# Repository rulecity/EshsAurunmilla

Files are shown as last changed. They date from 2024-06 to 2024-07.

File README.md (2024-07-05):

# Esh's Aurunmilla
(Mostly) 1:1 clone of the arcade game PCB for the Funai game, Esh's Aurunmilla

# Introduction
Esh's Aurunmilla was laserdisc game conversion for the 1983 Funai game Interstellar.  It is notoriously campy/cheesy with pretty bad voice acting.  In short, the game is so bad that it's good.

I became fascinated with this game some years ago and desired to own one.  Unfortunately, the PCB and laserdisc are both exceedingly rare.  So instead of finding originals of these items, I created reproductions.  I created a mostly 1:1 clone of the game PCB which is what this repository consists of.  After selling 20 of these clones to collectors and exhausting commercial demand, I decided to open source the whole thing for preservation.  What you have in this repository are the results of my efforts.

# PCBs
I created the PCB with Kicad v5.  I have tested these files on Kicad v6 and they seem to work fine.
I made two smaller PCBs to replace the original PROMs used on these games, which are very obsolete.  The small PCBs use CPLDs to mimic the behavior of the PROMs.  Unfortunately, these CPLDs have themselves become obsolete (I chose them because they were 5V tolerant on the inputs).  But someone who knows what they are doing should be able to update these with a new CPLD/FPGA if they want to badly enough.

I said before that the PCB is a mostly 1:1 clone.  I did change the laserdisc I/O port because the one on the original PCB was hopelessly non-standard.  I also removed some diagnostic stuff that was near the CPU on the original PCB as I saw no benefit to retaining it.  Otherwise, this clone should be nearly identical to the original, trace for trace.

# VHDL
I've included the simple VHDL source code programs I wrote for the two CPLDs.  I built with Xilinx ISE 14.7 which, last I checked, can be obtained for free as a linux VM that runs fine under Windows in VirtualBox.

# Bill of Materials
These are the actual spreadsheets I used when ordering parts for these PCBs.

# Test ROM
A test ROM I wrote from scratch to test PCBs before I shipped them off to customers.  Should be pretty comprehensive.

# More info
See http://www.rulecity.com/esh/

# Support
If you need help building the VHDL code, programming the CPLDs, or having PCBs made from the KiCad files, I offer commercial support: https://www.daphne-emu.com:9443/mediawiki/index.php/CommercialSupport

--Matt Ownby

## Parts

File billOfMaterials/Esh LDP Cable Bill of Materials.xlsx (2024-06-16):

Quantity | Reference | Manufacturer | Manufacturer Part Number | Distributor | Dist. Part Number | Note
1 |  |  |  |  | A1559-ND | LD-V1000 connector
1 |  |  |  |  | AE24G-300-ND | ribbon cable (300 feet)
1 |  |  |  |  | LKR26H-ND | female connector
 |  |  |  |  |  | 3.5 feet of ribbon per cable

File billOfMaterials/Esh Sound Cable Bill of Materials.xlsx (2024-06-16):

Quantity | Reference | Manufacturer | Manufacturer Part Number | Distributor | Dist. Part Number | Note
1 |  | JST | H4P-SHF-AA | Digikey | 455-4191-ND | 4-pin to sound PCB
1 |  | JST | H6P-SHF-AA | Digikey | 455-4193-ND | 6-pin to esh PCB
6 |  | JST | SHF-001T-0.8BS | Digikey | 455-1121-2-ND | JST pins (substitute: BHF-001T-0.8BS )
 |  |  |  |  |  | 2 feet of wires per cable
 |  |  |  |  |  | Pin 1 of the 6-pin connector is the audio signal and (I think) connects to pin 1 of the 4-pin connector.
 |  |  |  |  |  | Pins 2 and 4 are ground.
 |  |  |  |  |  | Pin 3 is the other audio channel used by Interstellar and is not used by Esh's so I leave it unconnected.

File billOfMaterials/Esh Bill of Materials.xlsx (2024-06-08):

Quantity | Reference | Manufacturer | Manufacturer Part Number | Distributor | Dist. Part Number | Note | Pins
1 |  |  |  | DigiKey | AE10008-ND | 40-pin socket
1 | L8 |  |  | jameco.com |  | Z80 CPU | 40
2 |  |  |  | DigiKey | AE10004-ND | 28-pin socket
2 | H8 F8 |  |  | jameco.com |  | 2764 | 28
5 |  |  |  | DigiKey | AE10001-ND | 24-pin socket
2 | J1 socket alternative |  |  | DigiKey | S7043-ND | To connect to PROM replacement PCB
1 | F3 |  |  | jameco.com |  | RAM 6116 150ms | 24
1 | B8 |  |  | jameco.com |  | RAM 6116 200ms | 24
3 | M3 L3 K3 |  |  | jameco.com |  | 2732 | 24
8 |  |  |  | DigiKey | AE9998-ND | 20-pin socket
3 | C1,C3,C4 |  |  | DigiKey | 296-1657-5-ND | 74LS273 | 20
2 | D4,F4 |  |  | DigiKey | 296-1655-5-ND | 74LS245 | 20
2 | F1 E1 |  |  | DigiKey | 296-1660-5-ND | 74LS373 | 20
1 | F7 |  |  | DigiKey | 296-1653-5-ND | 74LS244 | 20
0 | J1 |  | MB7124 |  |  | Use CPLD instead. PROM is too rare. | 20
28 |  |  |  | DigiKey | AE9992-ND | 16-pin socket
4 | C5,C6 socket alternative |  |  | DigiKey | S7041-ND | To connect to PROM replacement PCB
1 | B7 |  |  | DigiKey | 296-3702-5-ND | 74LS368 | 16
3 | A2,B2,C2 |  |  | DigiKey | 296-33981-5-ND | 74LS253 | 16
0 | C5,C6 |  | MB7052 | DigiKey |  | Use CPLD instead. PROMs overheat. | 16
1 | D2 |  |  | DigiKey | 497-2344-5-ND | ULN2003 | 16
6 | B6,B5,B4,B3,D7,C7 |  |  | DigiKey | 296-1646-5-ND | 74LS161 | 16
1 | D3 |  |  | DigiKey | 296-14889-5-ND | 74LS259 | 16
3 | D5 H5 J4 |  |  | DigiKey | 296-1640-5-ND | 74LS139 | 16
3 | E7 E6 E5 |  |  | DigiKey | 296-1645-5-ND | 74LS157 | 16
1 | H2 |  |  | DigiKey | 296-3654-5-ND | 74LS153 | 16
1 | H4 |  |  | DigiKey | 296-3664-5-ND | 74LS174 | 16
1 | H7 |  |  | DigiKey | 296-3701-5-ND | 74LS367 | 16
1 | J7 |  |  | DigiKey | 296-3655-5-ND | 74LS156 | 16
3 | K7 F6 F5 |  |  | DigiKey | 296-1639-5-ND | 74LS138 | 16
3 | M1 L1 K1 |  |  | DigiKey | 296-3662-5-ND | 74LS166 | 16
16 |  |  |  | DigiKey | AE9989-ND | 14-pin socket
2 | A2,A5 |  |  | DigiKey | 296-1633-5-ND | 74LS08 | 14
1 | A4 |  |  | DigiKey | 296-1669-5-ND | 74LS86 | 14
1 | A6 |  |  | DigiKey | 296-3693-5-ND | 74LS30 | 14
1 | D6 |  |  | DigiKey | 296-33952-5-ND | 74LS107 | 14
2 | F2 M5 |  |  | DigiKey | 296-1627-5-ND | 74LS02 | 14
2 | J5 K4 |  |  | DigiKey | 296-1658-5-ND | 74LS32 | 14
1 | J6 |  |  | DigiKey | 296-1626-ND | 74LS00 | 14
1 | K5 |  |  | DigiKey | 296-1634-5-ND | 74LS10 | 14
5 | L7 M7 M6 K6 H6 |  |  | DigiKey | 296-1668-5-ND | 74LS74 | 14
1 | BAT1 |  |  |  |  | 3-51FT-P
1 | CP1 |  |  | DigiKey | 493-1743-ND | 470uF, 16V. 8mm Diameter, 5mm Pin
1 | CP2 |  |  | DigiKey | 493-15966-1-ND | 10uF, 16V. 5mm diameter, 2.5mm pin
1 | CP27 |  |  | DigiKey | 399-14048-ND | 350pF
1 | CP28 |  |  | DigiKey | 399-8916-ND | 20pF, to match crystal. Mike Treu said 33pF worked better for him.
1 | CN1 | JST | B6P-SHF-1AA(LF)(SN) | DigiKey | 455-4181-ND | Audio connector
1 | CN5 | Amphenol | 71918-126LF | DigiKey | 609-1756-ND | LD-V1000 Connector
69 | CP# |  |  | DigiKey | 399-9759-ND | 0.1uF
1 | DIODE1 |  |  | DigiKey | BZX85C6V2-TAPGICT-ND | BZX85C6V2
2 | DIODE2,DIODE3 |  |  | DigiKey | 1N4148FS-ND | 1N4148
1 | Q1 | Microchip | MCP120-450GI/TO | DigiKey | MCP120-450GI/TO-ND
1 | R1 |  |  | DigiKey | CF14JT1K20CT-ND | 1.2k
1 | R13 |  |  | DigiKey | S100HCT-ND | 100 Ohm, 1/2W
5 | R17 R27 R22 R16 R9 |  |  | DigiKey | CF14JT1K00CT-ND | 1k
1 | R18 |  |  | DigiKey | CF14JT100RCT-ND | 100
3 | R2 R26 R25 |  |  | DigiKey | CF14JT10K0CT-ND | 10k
2 | R21 R20 |  |  | DigiKey | CF14JT330RCT-ND | 330
5 | R23 R19 R7 R6 R3 |  |  | DigiKey | CF14JT220RCT-ND | 220
4 | R8 R5 R4 R24 |  |  | DigiKey | CF14JT470RCT-ND | 470
4 | RA10 RA1 RA2 RA3 |  |  | DigiKey | 4609X-101-102LF-ND | 1k array
6 | RA4 RA7 RA5 RA8 RA6 RA9 |  |  | DigiKey | 770-83-R220P-ND | 220, series
1 | X1 | Fox | FC4STCBMF18.432-BAG200 | DigiKey | 631-1109-ND

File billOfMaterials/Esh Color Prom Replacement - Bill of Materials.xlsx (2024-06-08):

Quantity | Reference | Manufacturer | Manufacturer Part Number | Distributor | Dist. Part Number | Note
1 | U4 | TI | LMS8117AMP-3.3/NOPB | Digikey | LMS8117AMP-3.3/NOPBTR-ND | 3.3V reg
1 | U3 | Xilinx |  | Digikey | 122-1465-ND | CPLD
1 | R1 | Panasonic | ERJ-8GEYJ331V | Digikey | P330ECT-ND | 330 Ohm
3 | CP6, CP7, CP8 | Wurth | 885012208009 | Digikey | 732-8086-1-ND | 0.1 uF
2 | CP4,CP5, CP9 | Vishay | TL3A106K010C2000 | Digikey | 718-TL3A106K010C2000CT-ND | 10 uF as recommended by voltage reg; alternate non-polarized CL31B106KOHNFNE
1 | D1 | Kingbright Company LLC | APT3216SGC | Digi-Key | 754-1141-1-ND
2 | J1 pins alternate |  | M20-9731045 | Digikey | 952-1841-ND | Pairs with S7043-ND
1 | J2 |  |  | Digikey | 2057-PH2-14-UA-ND | JTAG Interface

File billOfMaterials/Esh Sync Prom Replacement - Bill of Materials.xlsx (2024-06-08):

Quantity | Reference | Manufacturer | Manufacturer Part Number | Distributor | Dist. Part Number | Note
1 | U4 |  |  | Digikey | 497-1241-1-ND | 3.3V reg
1 | U3 | Xilinx | XC9536XL-5VQG44C | Digikey | 122-1465-ND | CPLD
1 | R1 |  |  | Digikey | P330GCT-ND | 330 Ohm
4 | CP4, CP6, CP7, CP8 |  |  | Digikey | 720-1688-1-ND | 0.1 uF
2 | CP5, CP9 |  |  | Digikey | 490-12736-2-ND | 10 uF
1 | D1 | Kingbright Company LLC | APT3216SGC | Digi-Key | 754-1141-1-ND
4 | C5,C6 pins alternate |  |  | Digikey | 952-1999-ND | Pairs with S7041-ND
1 | J1 |  |  | Digikey | 2057-PH2-14-UA-ND | JTAG Interface

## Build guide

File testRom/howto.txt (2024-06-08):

Esh's Aurunmilla Test ROM Program v5
Written by Matt Ownby, Nov 2023
------------------------------------

I wrote this test ROM program in order to rapidly test reproduction Esh PCBs.

It tests almost everything on the PCB and presents the results on the screen.

The ROM test tests for the presence of a specific F8 Esh ROM that has the
 following MD5:

98ae491f23972416ef4edf5ae323a6a7  f8_is2.bin

TO ASSEMBLE:
------------

From ubuntu/bash:

$ sudo apt install z80asm m4
$ m4 esh_test.m4 > esh_test.asm
$ z80asm esh_test.asm -o h8_is1.bin

HOW TO USE:
-----------

- If you see "BAD RAM", then the CPU cannot read/write reliably to the RAM at B8.

- If the F8 ROM test fails, then CPU cannot confirm that the ROM shown above is installed at F8.

- If the strobe test fails, CPU is not getting status strobes from the LD-V1000 laserdisc player.  Check F2 and L7.

- If the LDP I/O test fails, CPU is not getting expected results from the LD-V1000 laserdisc player when trying to search to a specific frame. Check E1, F1 and F2.

- If the color palette and graphics shown at the top of the screen are unexpected, the color PROM and/or graphics EPROMs may have problems.

- If the background shown (either blue, black, or disc) is different from what the text is showing should be displyed, there may be a problem with the color PROM or H1.

- If you do not see "1X 2X 4X" text actively blinking, there may be a problem with H1.

- If you do not hear a beep when holding down the action button, there may be a problem with H1 or E2 or you do not have audio cable connected.

- If not all inputs are showing up when you press them on the control panel, there may be a problem with A2, B2, or C2.

- If the lamps indicated do not light up, there may be a problem with D2 or D3.

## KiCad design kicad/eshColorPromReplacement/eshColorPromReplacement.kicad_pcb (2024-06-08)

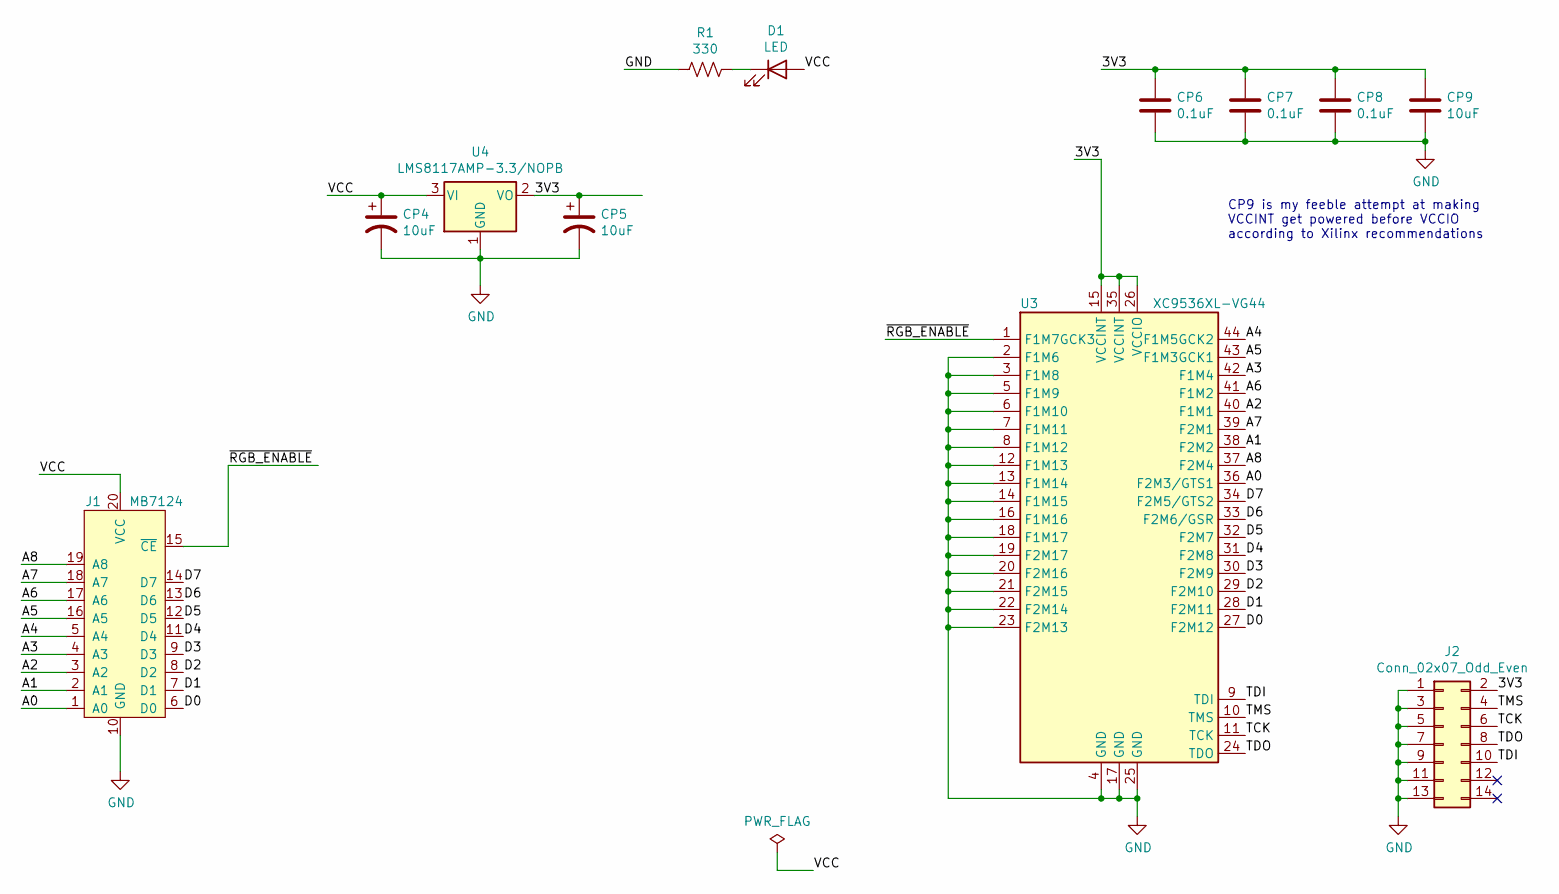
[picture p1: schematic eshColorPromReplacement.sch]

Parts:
CP4, CP5, CP9: 10uF; C_1206_3216Metric
CP6, CP7, CP8: 0.1uF; C_1206_3216Metric
D1: LED; LED_1206_3216Metric
J1: MB7124; DIP-20_W7.62mm_Socket
J2: Conn_02x07_Odd_Even; PinHeader_2x07_P2.54mm_Vertical
R1: 330; R_1206_3216Metric
U3: XC9536XL-VG44; TQFP-44_10x10mm_P0.8mm
U4: LMS8117AMP-3.3/NOPB; SOT-223-3_TabPin2

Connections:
/3V3: CP5.1, CP6.1, CP7.1, CP8.1, CP9.1, J2.2, U3.15 (VCCINT), U3.26 (VCCIO), U3.35 (VCCINT), U4.2 (VO)
/A0: J1.1 (A0), U3.36 (F2M3/GTS1)
/A1: J1.2 (A1), U3.38 (F2M2)
/A2: J1.3 (A2), U3.40 (F1M1)
/A3: J1.4 (A3), U3.42 (F1M4)
/A4: J1.5 (A4), U3.44 (F1M5GCK2)
/A5: J1.16 (A5), U3.43 (F1M3GCK1)
/A6: J1.17 (A6), U3.41 (F1M2)
/A7: J1.18 (A7), U3.39 (F2M1)
/A8: J1.19 (A8), U3.37 (F2M4)
/D0: J1.6 (D0), U3.27 (F2M12)
/D1: J1.7 (D1), U3.28 (F2M11)
/D2: J1.8 (D2), U3.29 (F2M10)
/D3: J1.9 (D3), U3.30 (F2M9)
/D4: J1.11 (D4), U3.31 (F2M8)
/D5: J1.12 (D5), U3.32 (F2M7)
/D6: J1.13 (D6), U3.33 (F2M6/GSR)
/D7: J1.14 (D7), U3.34 (F2M5/GTS2)
/TCK: J2.6, U3.11 (TCK)
/TDI: J2.10, U3.9 (TDI)
/TDO: J2.8, U3.24 (TDO)
/TMS: J2.4, U3.10 (TMS)
/VCC: CP4.1, D1.2 (A), J1.20 (VCC), U4.3 (VI)
/~RGB_ENABLE: J1.15 (~CE), U3.1 (F1M7GCK3)
GND: CP4.2, CP5.2, CP6.2, CP7.2, CP8.2, CP9.2, J1.10 (GND), J2.1, J2.3, J2.5, J2.7, J2.9, J2.11, J2.13, R1.2, U3.2 (F1M6), U3.3 (F1M8), U3.4 (GND), U3.5 (F1M9), U3.6 (F1M10), U3.7 (F1M11), U3.8 (F1M12), U3.12 (F1M13), U3.13 (F1M14), U3.14 (F1M15), U3.16 (F1M16), U3.17 (GND), U3.18 (F1M17), U3.19 (F2M17), U3.20 (F2M16), U3.21 (F2M15), U3.22 (F2M14), U3.23 (F2M13), U3.25 (GND), U4.1 (GND)
unnamed: D1.1 (K), R1.1

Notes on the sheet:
CP9 is my feeble attempt at making VCCINT get powered before VCCIO according to Xilinx recommendations

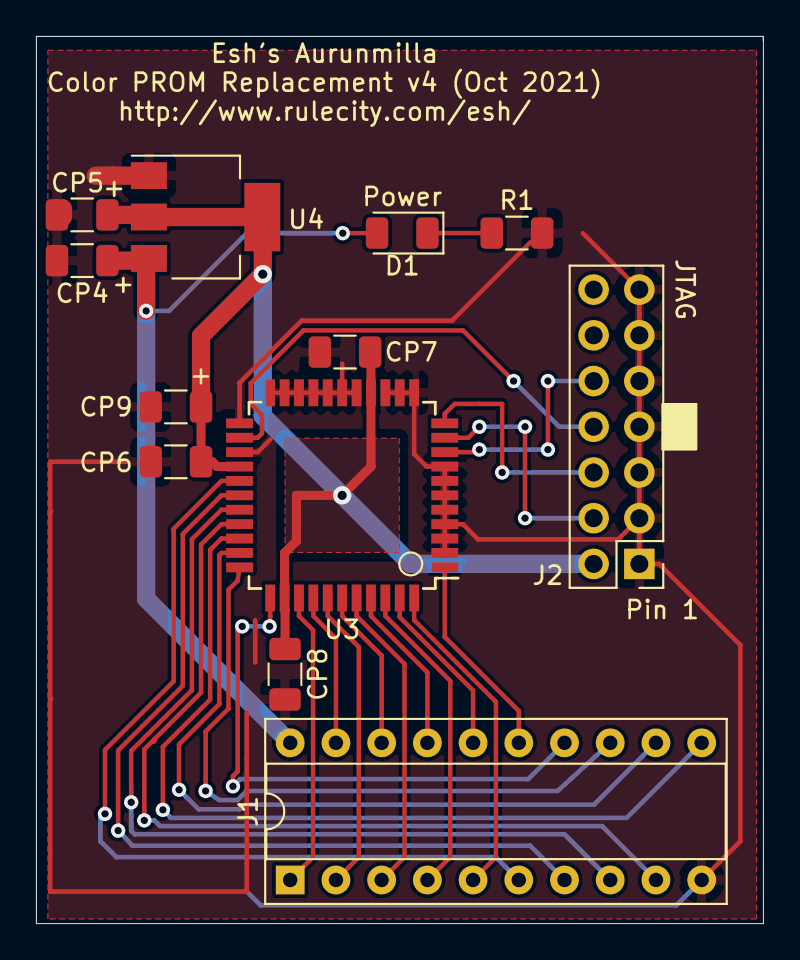
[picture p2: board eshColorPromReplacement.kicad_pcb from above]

Board: 2 copper layers, 40.4 x 49.3 mm, 12 parts (0 on the bottom side), 26 nets.

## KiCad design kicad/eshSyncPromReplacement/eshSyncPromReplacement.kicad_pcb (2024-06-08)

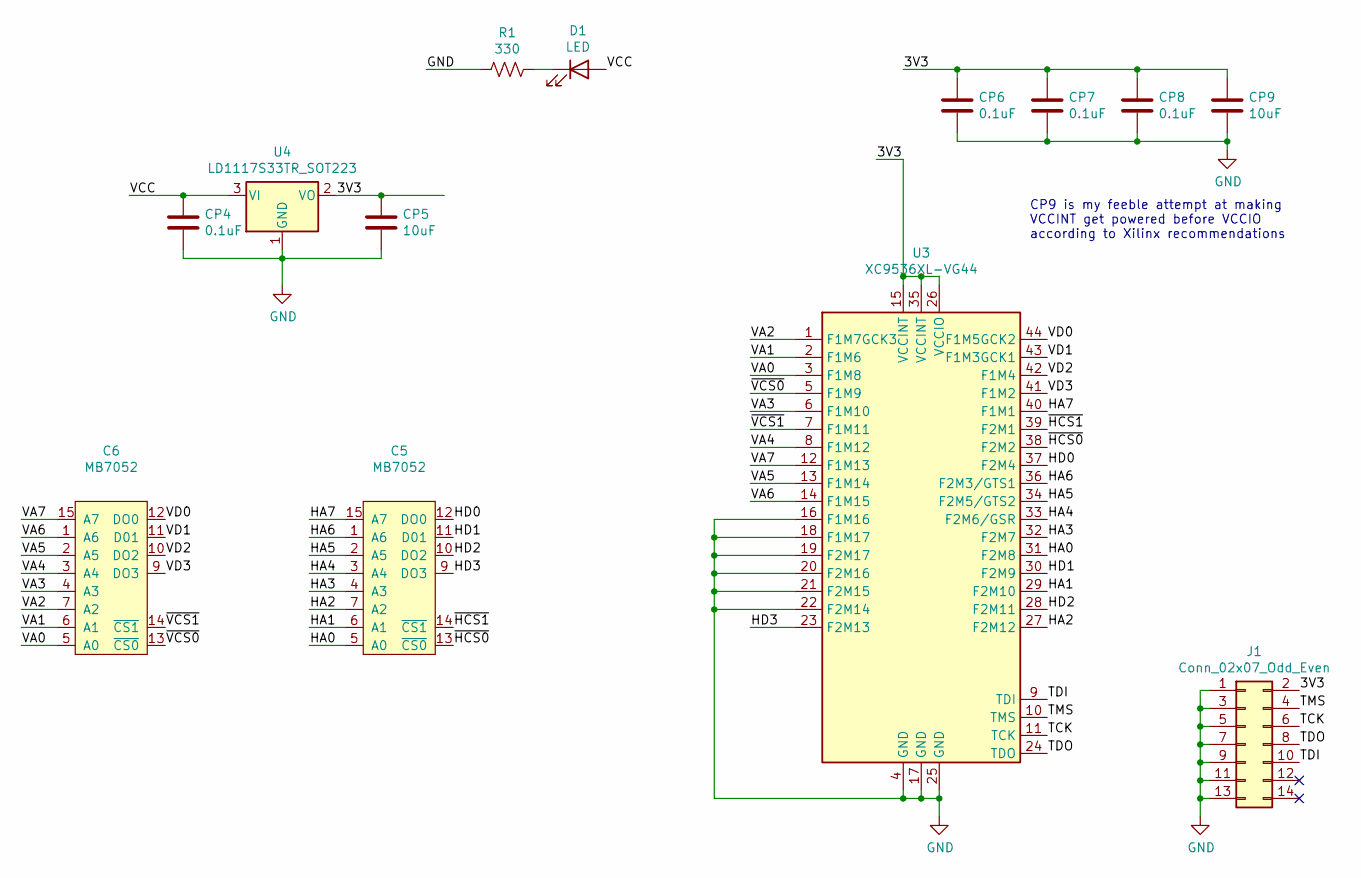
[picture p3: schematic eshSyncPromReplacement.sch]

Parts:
C5, C6: MB7052; DIP-16_W7.62mm_Socket
CP4, CP6, CP7, CP8: 0.1uF; C_0603_1608Metric
CP5, CP9: 10uF; C_0603_1608Metric
D1: LED; LED_1206_3216Metric
J1: Conn_02x07_Odd_Even; PinHeader_2x07_P2.54mm_Vertical
R1: 330; R_0603_1608Metric
U3: XC9536XL-VG44; TQFP-44_10x10mm_P0.8mm
U4: LD1117S33TR_SOT223; SOT-223-3_TabPin2

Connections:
/3V3: CP5.1, CP6.1, CP7.1, CP8.1, CP9.1, J1.2, U3.15 (VCCINT), U3.26 (VCCIO), U3.35 (VCCINT), U4.2 (VO)
/HA0: C5.5 (A0), U3.31 (F2M8)
/HA1: C5.6 (A1), U3.29 (F2M10)
/HA2: C5.7 (A2), U3.27 (F2M12)
/HA3: C5.4 (A3), U3.32 (F2M7)
/HA4: C5.3 (A4), U3.33 (F2M6/GSR)
/HA5: C5.2 (A5), U3.34 (F2M5/GTS2)
/HA6: C5.1 (A6), U3.36 (F2M3/GTS1)
/HA7: C5.15 (A7), U3.40 (F1M1)
/HD0: C5.12 (DO0), U3.37 (F2M4)
/HD1: C5.11 (D01), U3.30 (F2M9)
/HD2: C5.10 (DO2), U3.28 (F2M11)
/HD3: C5.9 (DO3), U3.23 (F2M13)
/TCK: J1.6, U3.11 (TCK)
/TDI: J1.10, U3.9 (TDI)
/TDO: J1.8, U3.24 (TDO)
/TMS: J1.4, U3.10 (TMS)
/VA0: C6.5 (A0), U3.3 (F1M8)
/VA1: C6.6 (A1), U3.2 (F1M6)
/VA2: C6.7 (A2), U3.1 (F1M7GCK3)
/VA3: C6.4 (A3), U3.6 (F1M10)
/VA4: C6.3 (A4), U3.8 (F1M12)
/VA5: C6.2 (A5), U3.13 (F1M14)
/VA6: C6.1 (A6), U3.14 (F1M15)
/VA7: C6.15 (A7), U3.12 (F1M13)
/VD0: C6.12 (DO0), U3.44 (F1M5GCK2)
/VD1: C6.11 (D01), U3.43 (F1M3GCK1)
/VD2: C6.10 (DO2), U3.42 (F1M4)
/VD3: C6.9 (DO3), U3.41 (F1M2)
/~HCS0: C5.13 (~CS0), U3.38 (F2M2)
/~HCS1: C5.14 (~CS1), U3.39 (F2M1)
/~VCS0: C6.13 (~CS0), U3.5 (F1M9)
/~VCS1: C6.14 (~CS1), U3.7 (F1M11)
GND: C5.8 (GND), C6.8 (GND), CP4.2, CP5.2, CP6.2, CP7.2, CP8.2, CP9.2, J1.1, J1.3, J1.5, J1.7, J1.9, J1.11, J1.13, R1.2, U3.4 (GND), U3.16 (F1M16), U3.17 (GND), U3.18 (F1M17), U3.19 (F2M17), U3.20 (F2M16), U3.21 (F2M15), U3.22 (F2M14), U3.25 (GND), U4.1 (GND)
unnamed: D1.1 (K), R1.1
VCC: C5.16 (VCC), C6.16 (VCC), CP4.1, D1.2 (A), U4.3 (VI)

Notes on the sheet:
CP9 is my feeble attempt at making VCCINT get powered before VCCIO according to Xilinx recommendations

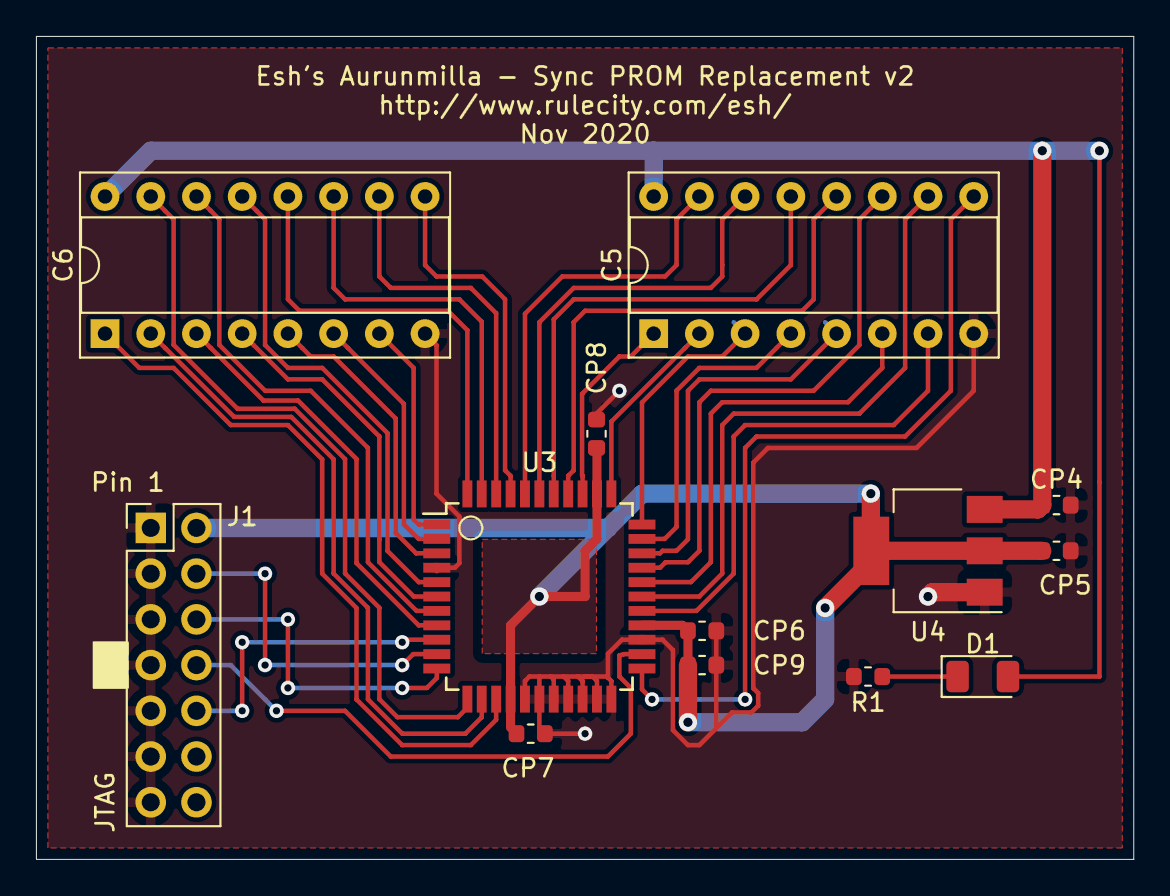
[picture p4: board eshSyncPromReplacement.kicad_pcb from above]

Board: 2 copper layers, 61.0 x 45.7 mm, 13 parts (0 on the bottom side), 36 nets.

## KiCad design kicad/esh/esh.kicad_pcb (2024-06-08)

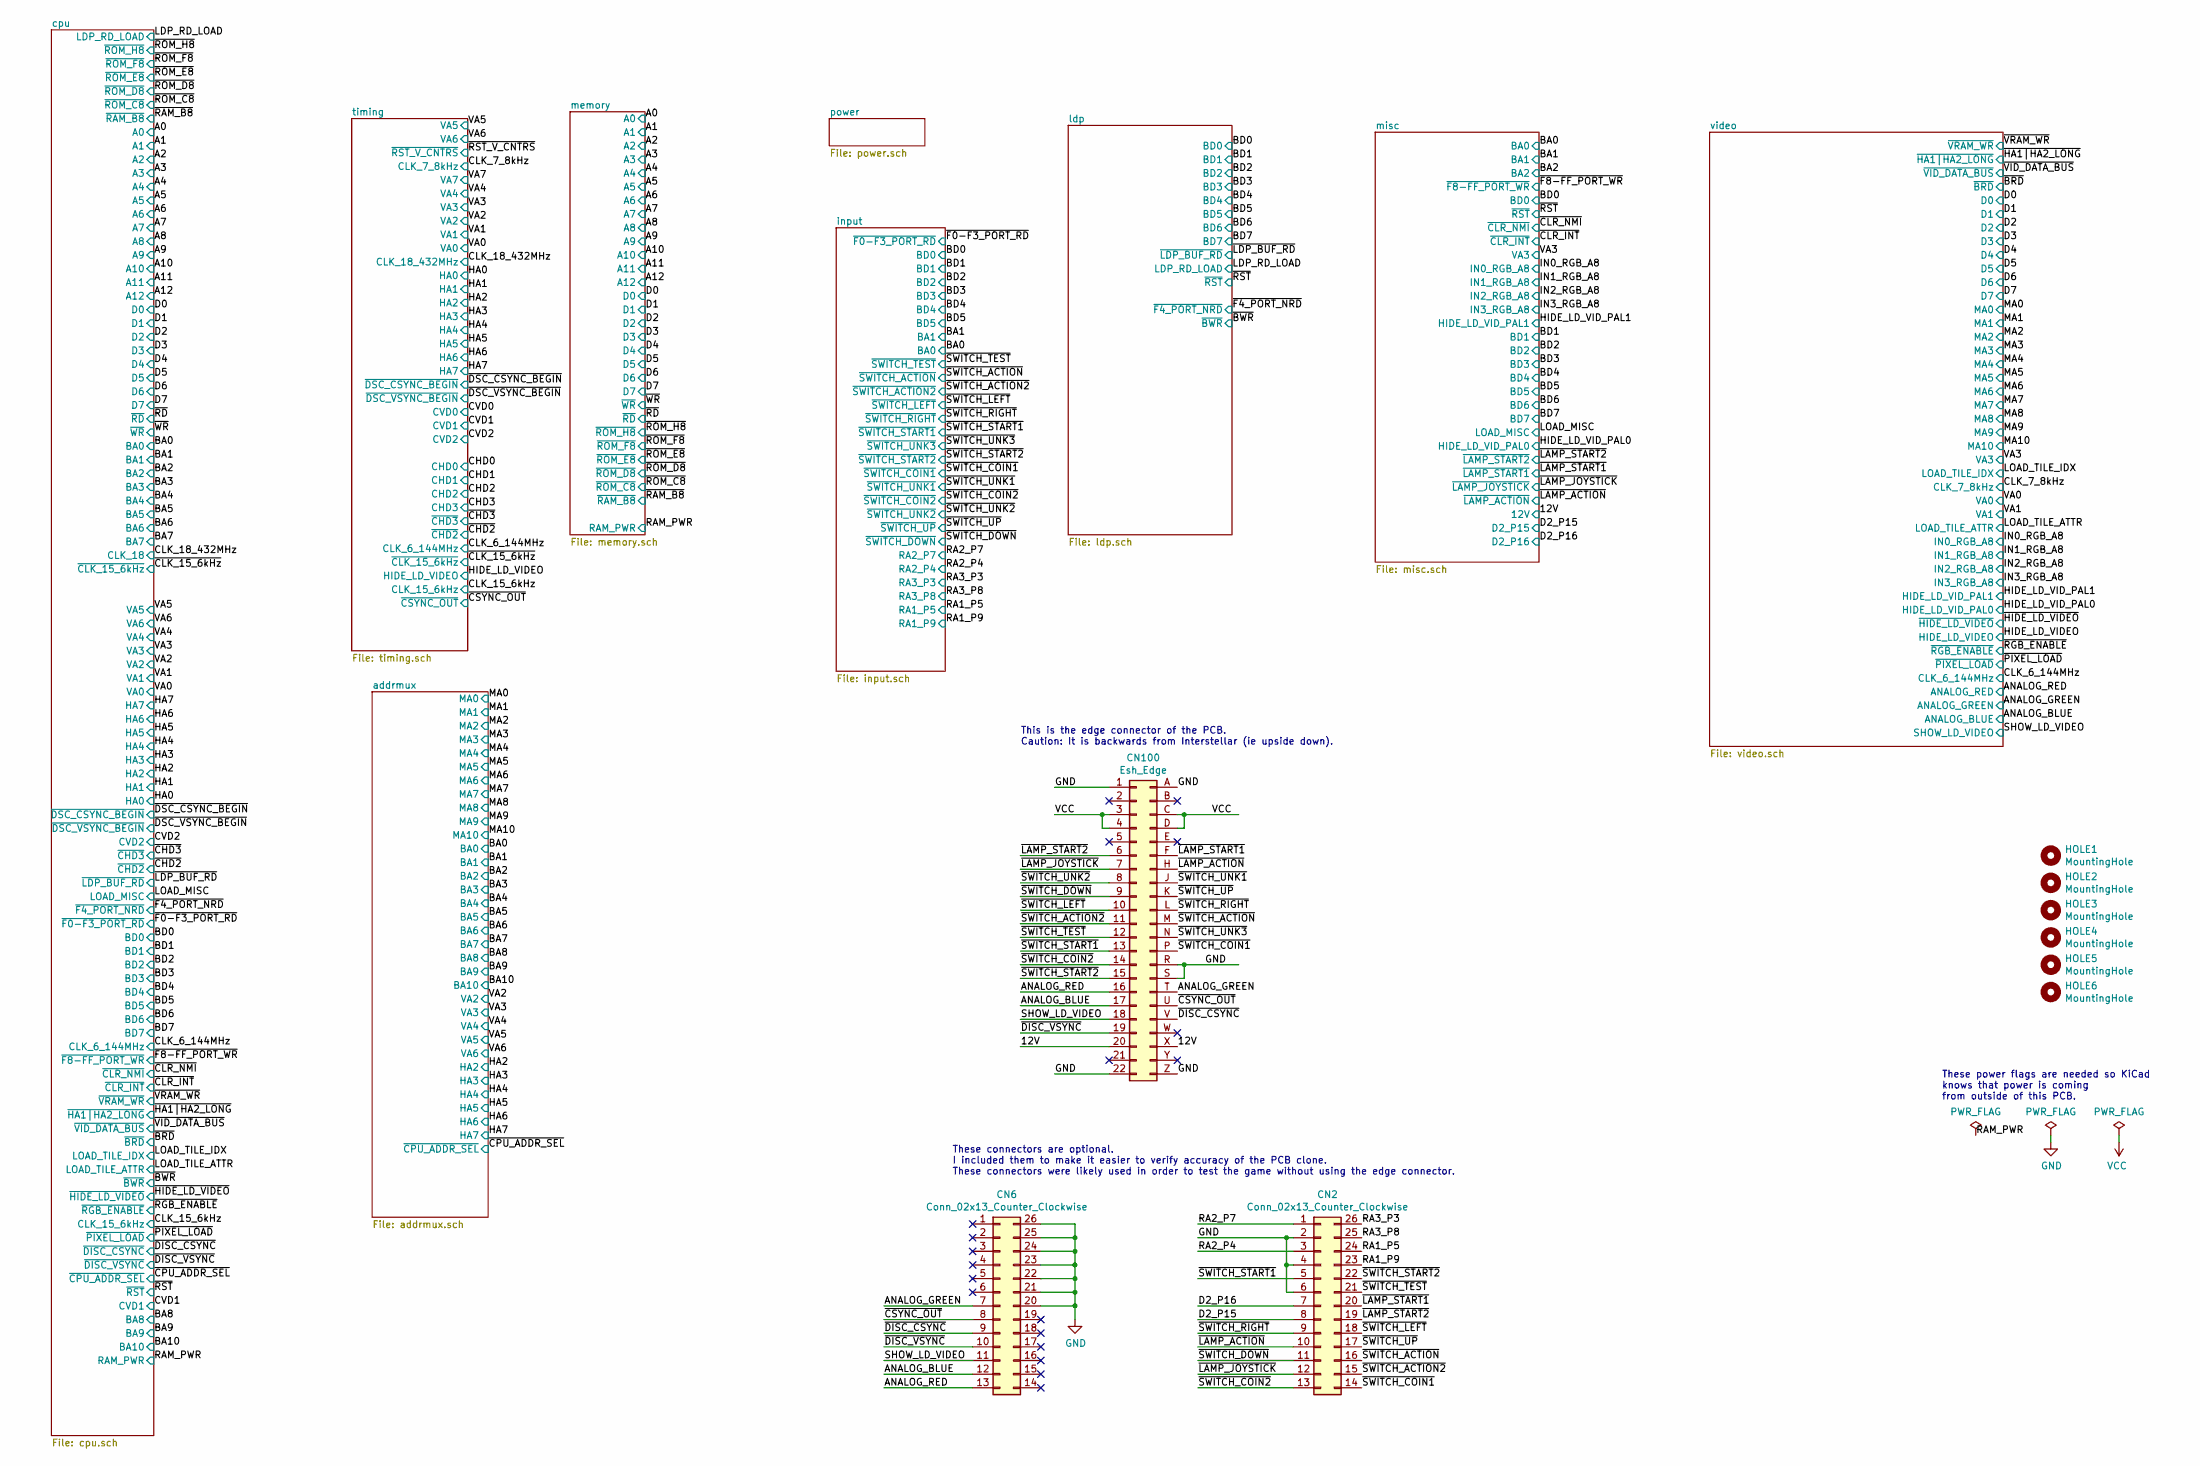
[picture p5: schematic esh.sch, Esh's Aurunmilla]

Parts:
CN2, CN6: Conn_02x13_Counter_Clockwise; 2x13Connector
CN100: Esh_Edge
HOLE1, HOLE2, HOLE3, HOLE4, HOLE5, HOLE6: MountingHole; MountingHole_4mm

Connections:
/12V: CN100.20, CN100.X; also elsewhere on the board
/ANALOG_BLUE: CN6.12, CN100.17; also elsewhere on the board
/ANALOG_GREEN: CN6.7, CN100.T; also elsewhere on the board
/ANALOG_RED: CN6.13, CN100.16; also elsewhere on the board
/D2_P15: CN2.8; also elsewhere on the board
/D2_P16: CN2.7; also elsewhere on the board
/RA1_P5: CN2.24; also elsewhere on the board
/RA1_P9: CN2.23; also elsewhere on the board
/RA2_P4: CN2.3; also elsewhere on the board
/RA2_P7: CN2.1; also elsewhere on the board
/RA3_P3: CN2.26; also elsewhere on the board
/RA3_P8: CN2.25; also elsewhere on the board
/SHOW_LD_VIDEO: CN6.11, CN100.18; also elsewhere on the board
/~CSYNC_OUT: CN6.8, CN100.U; also elsewhere on the board
/~DISC_CSYNC: CN6.9, CN100.V; also elsewhere on the board
/~DISC_VSYNC: CN6.10, CN100.19; also elsewhere on the board
/~LAMP_ACTION: CN2.10, CN100.H; also elsewhere on the board
/~LAMP_JOYSTICK: CN2.12, CN100.7; also elsewhere on the board
/~LAMP_START1: CN2.20, CN100.F; also elsewhere on the board
/~LAMP_START2: CN2.19, CN100.6; also elsewhere on the board
/~SWITCH_ACTION: CN2.16, CN100.M; also elsewhere on the board
/~SWITCH_ACTION2: CN2.15, CN100.11; also elsewhere on the board
/~SWITCH_COIN1: CN2.14, CN100.P; also elsewhere on the board
/~SWITCH_COIN2: CN2.13, CN100.14; also elsewhere on the board
/~SWITCH_DOWN: CN2.11, CN100.9; also elsewhere on the board
/~SWITCH_LEFT: CN2.18, CN100.10; also elsewhere on the board
/~SWITCH_RIGHT: CN2.9, CN100.L; also elsewhere on the board
/~SWITCH_START1: CN2.5, CN100.13; also elsewhere on the board
/~SWITCH_START2: CN2.22, CN100.15; also elsewhere on the board
/~SWITCH_TEST: CN2.21, CN100.12; also elsewhere on the board
/~SWITCH_UNK1: CN100.J; also elsewhere on the board
/~SWITCH_UNK2: CN100.8; also elsewhere on the board
/~SWITCH_UNK3: CN100.N; also elsewhere on the board
/~SWITCH_UP: CN2.17, CN100.K; also elsewhere on the board
GND: CN2.2, CN2.4, CN2.6, CN6.20, CN6.21, CN6.22, CN6.23, CN6.24, CN6.25, CN6.26, CN100.1, CN100.22, CN100.A, CN100.R, CN100.S, CN100.Z; also elsewhere on the board
VCC: CN100.3, CN100.4, CN100.C, CN100.D; also elsewhere on the board

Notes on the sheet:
These power flags are needed so KiCad knows that power is coming from outside of this PCB.
These connectors are optional. I included them to make it easier to verify accuracy of the PCB clone. These connectors were likely used in order to test the game without using the edge connector.
This is the edge connector of the PCB. Caution: It is backwards from Interstellar (ie upside down).

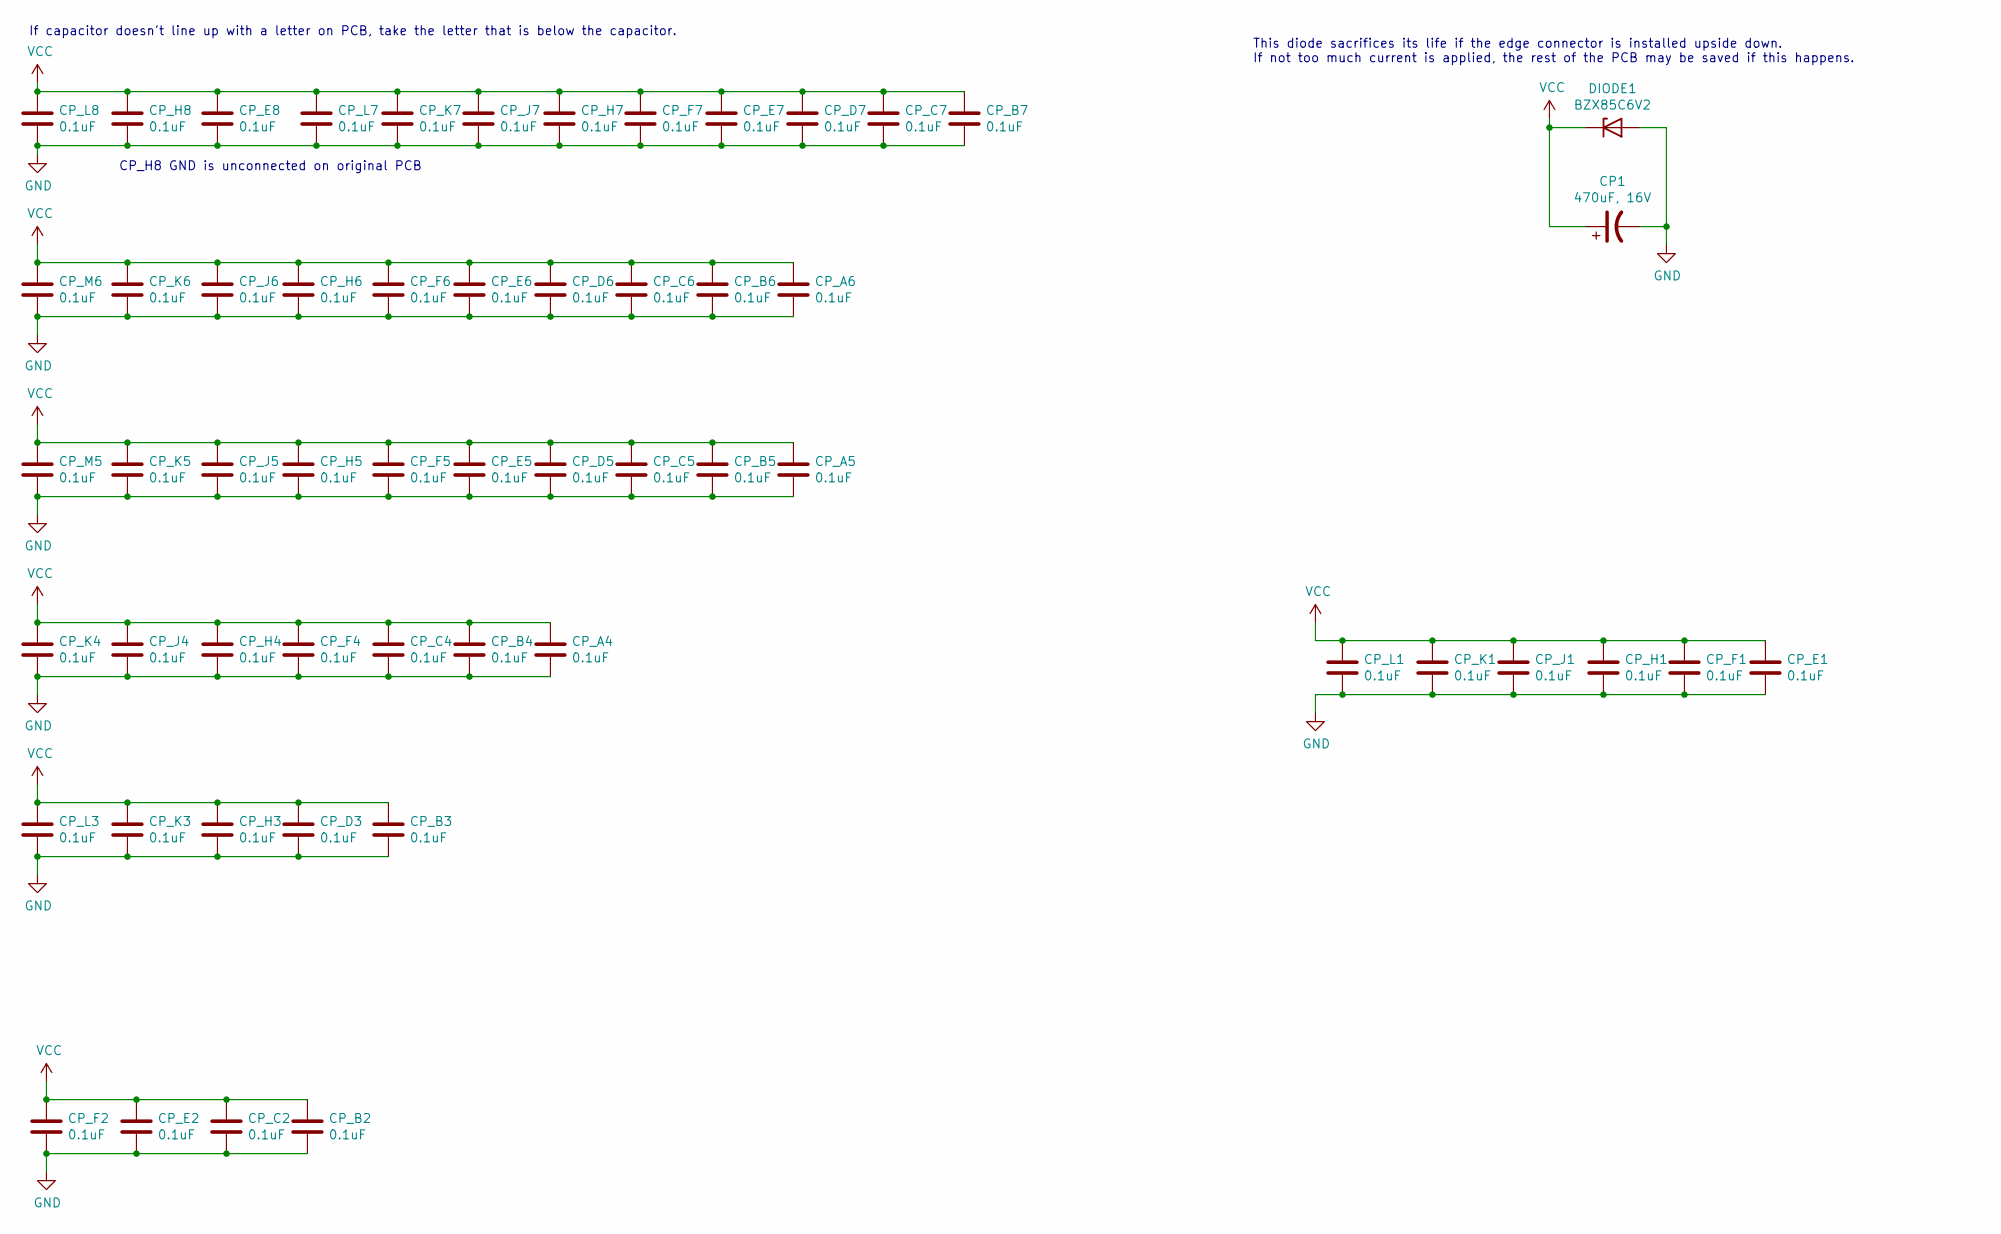
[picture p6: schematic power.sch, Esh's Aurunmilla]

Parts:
CP1: 470uF, 16V; CP_Radial_D8.0mm_P5.00mm
CP_A4, CP_A5, CP_A6: 0.1uF; R_Axial_DIN0204_L3.6mm_D1.6mm_P5.08mm_Horizontal
CP_B2, CP_B3, CP_B4, CP_B5, CP_B6, CP_B7: 0.1uF; R_Axial_DIN0204_L3.6mm_D1.6mm_P5.08mm_Horizontal
CP_C2, CP_C4, CP_C5, CP_C6, CP_C7: 0.1uF; R_Axial_DIN0204_L3.6mm_D1.6mm_P5.08mm_Horizontal
CP_D3, CP_D5, CP_D6, CP_D7: 0.1uF; R_Axial_DIN0204_L3.6mm_D1.6mm_P5.08mm_Horizontal
CP_E1, CP_E2, CP_E5, CP_E6, CP_E7, CP_E8: 0.1uF; R_Axial_DIN0204_L3.6mm_D1.6mm_P5.08mm_Horizontal
CP_F1, CP_F2, CP_F4, CP_F5, CP_F6, CP_F7: 0.1uF; R_Axial_DIN0204_L3.6mm_D1.6mm_P5.08mm_Horizontal
CP_H1, CP_H3, CP_H4, CP_H5, CP_H6, CP_H7, CP_H8: 0.1uF; R_Axial_DIN0204_L3.6mm_D1.6mm_P5.08mm_Horizontal
CP_J1, CP_J4, CP_J5, CP_J6, CP_J7: 0.1uF; R_Axial_DIN0204_L3.6mm_D1.6mm_P5.08mm_Horizontal
CP_K1, CP_K3, CP_K4, CP_K5, CP_K6, CP_K7: 0.1uF; R_Axial_DIN0204_L3.6mm_D1.6mm_P5.08mm_Horizontal
CP_L1, CP_L3, CP_L7, CP_L8: 0.1uF; R_Axial_DIN0204_L3.6mm_D1.6mm_P5.08mm_Horizontal
CP_M5, CP_M6: 0.1uF; R_Axial_DIN0204_L3.6mm_D1.6mm_P5.08mm_Horizontal
DIODE1: BZX85C6V2; D_T-1_P10.16mm_Horizontal

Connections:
GND: CP1.2, CP_A4.2, CP_A5.2, CP_A6.2, CP_B2.2, CP_B3.2, CP_B4.2, CP_B5.2, CP_B6.2, CP_B7.2, CP_C2.2, CP_C4.2, CP_C5.2, CP_C6.2, CP_C7.2, CP_D3.2, CP_D5.2, CP_D6.2, CP_D7.2, CP_E1.2, CP_E2.2, CP_E5.2, CP_E6.2, CP_E7.2, CP_E8.2, CP_F1.2, CP_F2.2, CP_F4.2, CP_F5.2, CP_F6.2, CP_F7.2, CP_H1.2, CP_H3.2, CP_H4.2, CP_H5.2, CP_H6.2, CP_H7.2, CP_H8.2, CP_J1.2, CP_J4.2, CP_J5.2, CP_J6.2, CP_J7.2, CP_K1.2, CP_K3.2, CP_K4.2, CP_K5.2, CP_K6.2, CP_K7.2, CP_L1.2, CP_L3.2, CP_L7.2, CP_L8.2, CP_M5.2, CP_M6.2, DIODE1.2 (A); also elsewhere on the board
VCC: CP1.1, CP_A4.1, CP_A5.1, CP_A6.1, CP_B2.1, CP_B3.1, CP_B4.1, CP_B5.1, CP_B6.1, CP_B7.1, CP_C2.1, CP_C4.1, CP_C5.1, CP_C6.1, CP_C7.1, CP_D3.1, CP_D5.1, CP_D6.1, CP_D7.1, CP_E1.1, CP_E2.1, CP_E5.1, CP_E6.1, CP_E7.1, CP_E8.1, CP_F1.1, CP_F2.1, CP_F4.1, CP_F5.1, CP_F6.1, CP_F7.1, CP_H1.1, CP_H3.1, CP_H4.1, CP_H5.1, CP_H6.1, CP_H7.1, CP_H8.1, CP_J1.1, CP_J4.1, CP_J5.1, CP_J6.1, CP_J7.1, CP_K1.1, CP_K3.1, CP_K4.1, CP_K5.1, CP_K6.1, CP_K7.1, CP_L1.1, CP_L3.1, CP_L7.1, CP_L8.1, CP_M5.1, CP_M6.1, DIODE1.1 (K); also elsewhere on the board

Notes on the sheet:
If capacitor doesn't line up with a letter on PCB, take the letter that is below the capacitor.
CP_H8 GND is unconnected on original PCB
This diode sacrifices its life if the edge connector is installed upside down. If not too much current is applied, the rest of the PCB may be saved if this happens.

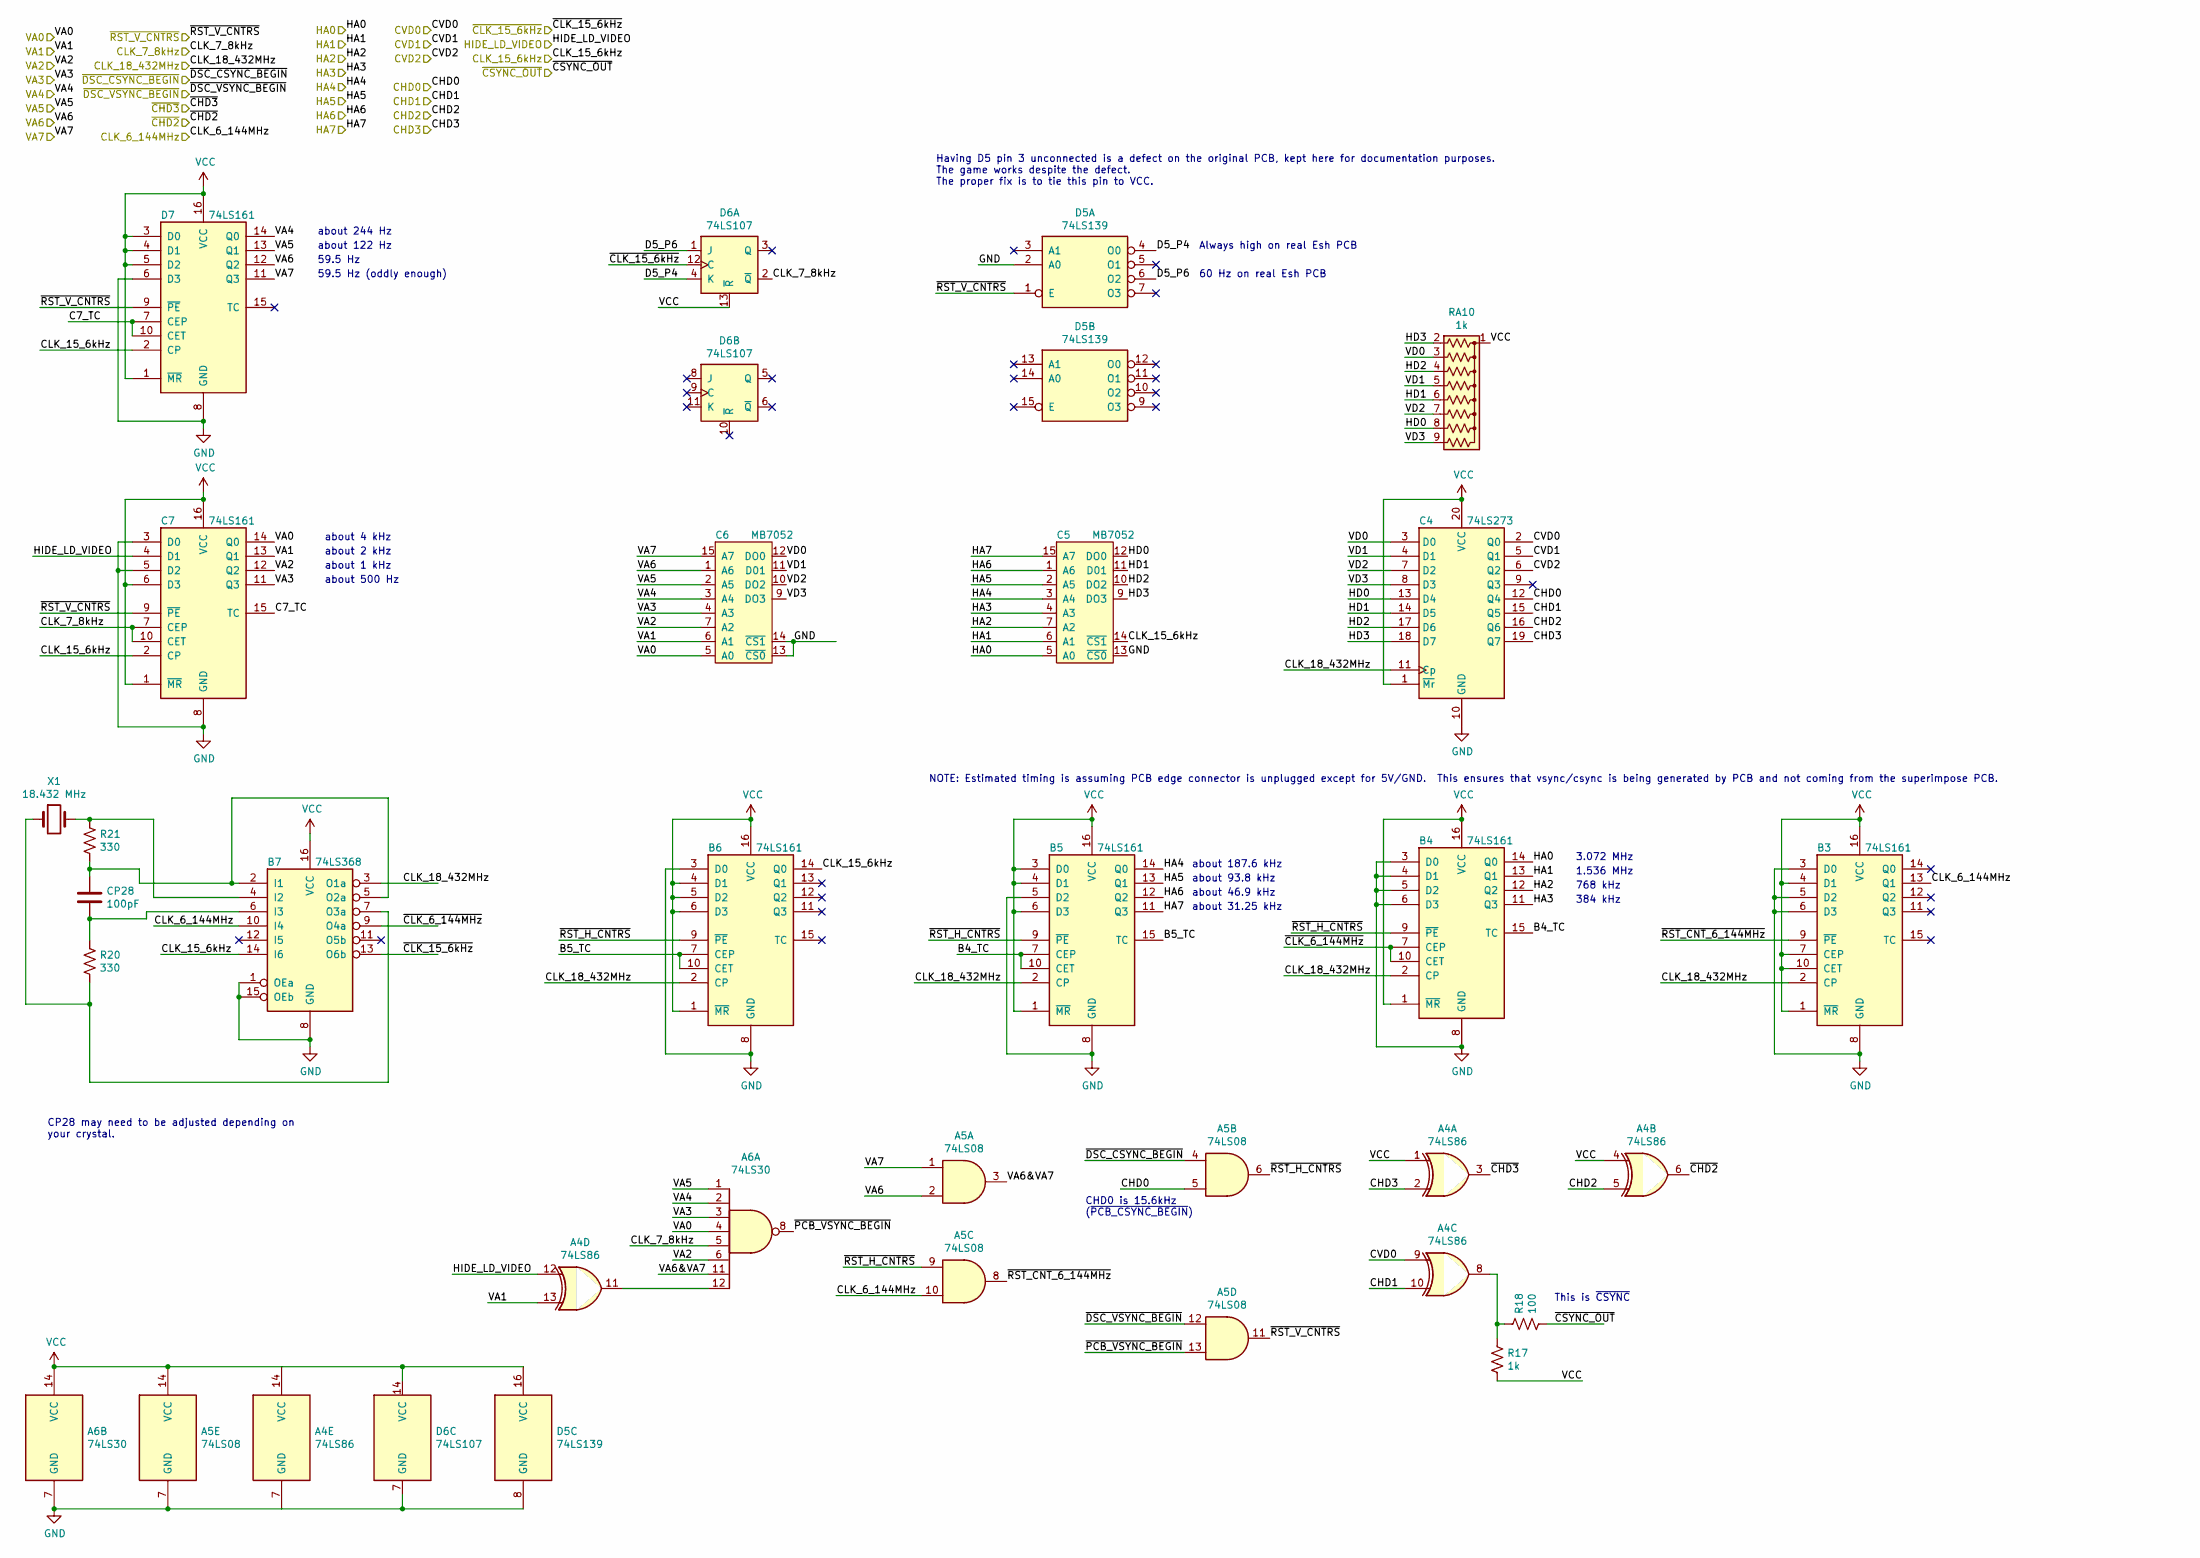
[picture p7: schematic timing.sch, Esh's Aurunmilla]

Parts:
A4: 74LS86; DIP-14_W7.62mm_Socket
A5: 74LS08; DIP-14_W7.62mm_Socket
A6: 74LS30; DIP-14_W7.62mm_Socket
B3, B4, B5, B6: 74LS161; DIP-16_W7.62mm_Socket
B7: 74LS368; DIP-16_W7.62mm_Socket
C4: 74LS273; DIP-20_W7.62mm_Socket
C5, C6: MB7052; DIP-16_W7.62mm_Socket
C7: 74LS161; DIP-16_W7.62mm_Socket
CP28: 100pF; R_Axial_DIN0204_L3.6mm_D1.6mm_P5.08mm_Horizontal
D5: 74LS139; DIP-16_W7.62mm_Socket
D6: 74LS107; DIP-14_W7.62mm_Socket
D7: 74LS161; DIP-16_W7.62mm_Socket
R17: 1k; R_Axial_DIN0207_L6.3mm_D2.5mm_P10.16mm_Horizontal
R18: 100; R_Axial_DIN0207_L6.3mm_D2.5mm_P10.16mm_Horizontal
R20, R21: 330; R_Axial_DIN0207_L6.3mm_D2.5mm_P10.16mm_Horizontal
RA10: 1k; R_Array_SIP9
X1: 18.432 MHz; Crystal_HC49-U_Vertical

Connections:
/CHD0: A5.5, C4.12 (Q4)
/CHD1: A4.10, C4.15 (Q5)
/CHD2: A4.5, C4.16 (Q6)
/CHD3: A4.2, C4.19 (Q7)
/CLK_6_144MHz: A5.10, B3.13 (Q1), B7.10 (I4); also elsewhere on the board
/CLK_7_8kHz: A6.5, C7.7 (CEP), C7.10 (CET), D6.2 (~Q); also elsewhere on the board
/CLK_15_6kHz: B6.14 (Q0), B7.14 (I6), C5.14 (~CS1), C7.2 (CP), D7.2 (CP); also elsewhere on the board
/CLK_18_432MHz: B3.2 (CP), B4.2 (CP), B5.2 (CP), B6.2 (CP), B7.3 (O1a), C4.11 (Cp); also elsewhere on the board
/CVD0: A4.9, C4.2 (Q0)
/CVD1: C4.5 (Q1); also elsewhere on the board
/CVD2: C4.6 (Q2); also elsewhere on the board
/HA0: B4.14 (Q0), C5.5 (A0); also elsewhere on the board
/HA1: B4.13 (Q1), C5.6 (A1); also elsewhere on the board
/HA2: B4.12 (Q2), C5.7 (A2); also elsewhere on the board
/HA3: B4.11 (Q3), C5.4 (A3); also elsewhere on the board
/HA4: B5.14 (Q0), C5.3 (A4); also elsewhere on the board
/HA5: B5.13 (Q1), C5.2 (A5); also elsewhere on the board
/HA6: B5.12 (Q2), C5.1 (A6); also elsewhere on the board
/HA7: B5.11 (Q3), C5.15 (A7); also elsewhere on the board
/HIDE_LD_VIDEO: A4.12, C7.4 (D1); also elsewhere on the board
/VA0: A6.4, C6.5 (A0), C7.14 (Q0); also elsewhere on the board
/VA1: A4.13, C6.6 (A1), C7.13 (Q1); also elsewhere on the board
/VA2: A6.6, C6.7 (A2), C7.12 (Q2); also elsewhere on the board
/VA3: A6.3, C6.4 (A3), C7.11 (Q3); also elsewhere on the board
/VA4: A6.2, C6.3 (A4), D7.14 (Q0); also elsewhere on the board
/VA5: A6.1, C6.2 (A5), D7.13 (Q1); also elsewhere on the board
/VA6: A5.2, C6.1 (A6), D7.12 (Q2); also elsewhere on the board
/VA7: A5.1, C6.15 (A7), D7.11 (Q3)
/timing/B4_TC: B4.15 (TC), B5.7 (CEP), B5.10 (CET)
/timing/B5_TC: B5.15 (TC), B6.7 (CEP), B6.10 (CET)
/timing/C7_TC: C7.15 (TC), D7.7 (CEP), D7.10 (CET)
/timing/D5_P4: D5.4 (O0), D6.4 (K)
/timing/D5_P6: D5.6 (O2), D6.1 (J)
/timing/HD0: C4.13 (D4), C5.12 (DO0), RA10.8 (R7)
/timing/HD1: C4.14 (D5), C5.11 (D01), RA10.6 (R5)
/timing/HD2: C4.17 (D6), C5.10 (DO2), RA10.4 (R3)
/timing/HD3: C4.18 (D7), C5.9 (DO3), RA10.2 (R1)
/timing/VA6&VA7: A5.3, A6.11
/timing/VD0: C4.3 (D0), C6.12 (DO0), RA10.3 (R2)
/timing/VD1: C4.4 (D1), C6.11 (D01), RA10.5 (R4)
/timing/VD2: C4.7 (D2), C6.10 (DO2), RA10.7 (R6)
/timing/VD3: C4.8 (D3), C6.9 (DO3), RA10.9 (R8)
/timing/~CLK_6_144MHz: B4.7 (CEP), B4.10 (CET), B7.9 (O4a)
/timing/~PCB_VSYNC_BEGIN: A5.13, A6.8
/timing/~RST_CNT_6_144MHz: A5.8, B3.9 (~PE)
/timing/~RST_H_CNTRS: A5.6, A5.9, B4.9 (~PE), B5.9 (~PE), B6.9 (~PE)
/~CHD2: A4.6; also elsewhere on the board
/~CHD3: A4.3; also elsewhere on the board
/~CLK_15_6kHz: B7.13 (O6b), D6.12 (C); also elsewhere on the board
/~CSYNC_OUT: R18.1; also elsewhere on the board
/~DSC_CSYNC_BEGIN: A5.4; also elsewhere on the board
/~DSC_VSYNC_BEGIN: A5.12; also elsewhere on the board
/~RST_V_CNTRS: A5.11, C7.9 (~PE), D5.1 (E), D7.9 (~PE)
GND: A4.7 (GND), A5.7 (GND), A6.7 (GND), B3.3 (D0), B3.5 (D2), B3.6 (D3), B3.8 (GND), B4.3 (D0), B4.4 (D1), B4.5 (D2), B4.6 (D3), B4.8 (GND), B5.5 (D2), B5.8 (GND), B6.3 (D0), B6.8 (GND), B7.1 (OEa), B7.8 (GND), B7.15 (OEb), C4.10 (GND), C5.8 (GND), C5.13 (~CS0), C6.8 (GND), C6.13 (~CS0), C6.14 (~CS1), C7.3 (D0), C7.5 (D2), C7.8 (GND), D5.2 (A0), D5.8 (GND), D6.7 (GND), D7.6 (D3), D7.8 (GND); also elsewhere on the board
unnamed: A4.8, R17.2, R18.2
unnamed: A4.11, A6.12
unnamed: B7.2 (I1), B7.5 (O2a), CP28.1, R21.1
unnamed: B7.4 (I2), R21.2, X1.2
unnamed: B7.6 (I3), CP28.2, R20.2
unnamed: B7.7 (O3a), R20.1, X1.1
VCC: A4.1, A4.4, A4.14 (VCC), A5.14 (VCC), A6.14 (VCC), B3.1 (~MR), B3.4 (D1), B3.7 (CEP), B3.10 (CET), B3.16 (VCC), B4.1 (~MR), B4.16 (VCC), B5.1 (~MR), B5.3 (D0), B5.4 (D1), B5.6 (D3), B5.16 (VCC), B6.1 (~MR), B6.4 (D1), B6.5 (D2), B6.6 (D3), B6.16 (VCC), B7.16 (VCC), C4.1 (~Mr), C4.20 (VCC), C5.16 (VCC), C6.16 (VCC), C7.1 (~MR), C7.6 (D3), C7.16 (VCC), D5.16 (VCC), D6.13 (~R), D6.14 (VCC), D7.1 (~MR), D7.3 (D0), D7.4 (D1), D7.5 (D2), D7.16 (VCC), R17.1, RA10.1 (common); also elsewhere on the board

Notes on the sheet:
Always high on real Esh PCB
60 Hz on real Esh PCB
3.072 MHz
1.536 MHz
768 kHz
384 kHz
about 31.25 kHz
about 46.9 kHz
about 93.8 kHz
about 187.6 kHz
about 244 Hz
about 122 Hz
59.5 Hz
59.5 Hz (oddly enough)
about 4 kHz
about 2 kHz
about 1 kHz
about 500 Hz
CHD0 is 15.6kHz (~PCB_CSYNC_BEGIN)
This is ~CSYNC
Having D5 pin 3 unconnected is a defect on the original PCB, kept here for documentation purposes. The game works despite the defect. The proper fix is to tie this pin to VCC.
CP28 may need to be adjusted depending on your crystal.
NOTE: Estimated timing is assuming PCB edge connector is unplugged except for 5V/GND. This ensures that vsync/csync is being generated by PCB and not coming from the superimpose PCB.

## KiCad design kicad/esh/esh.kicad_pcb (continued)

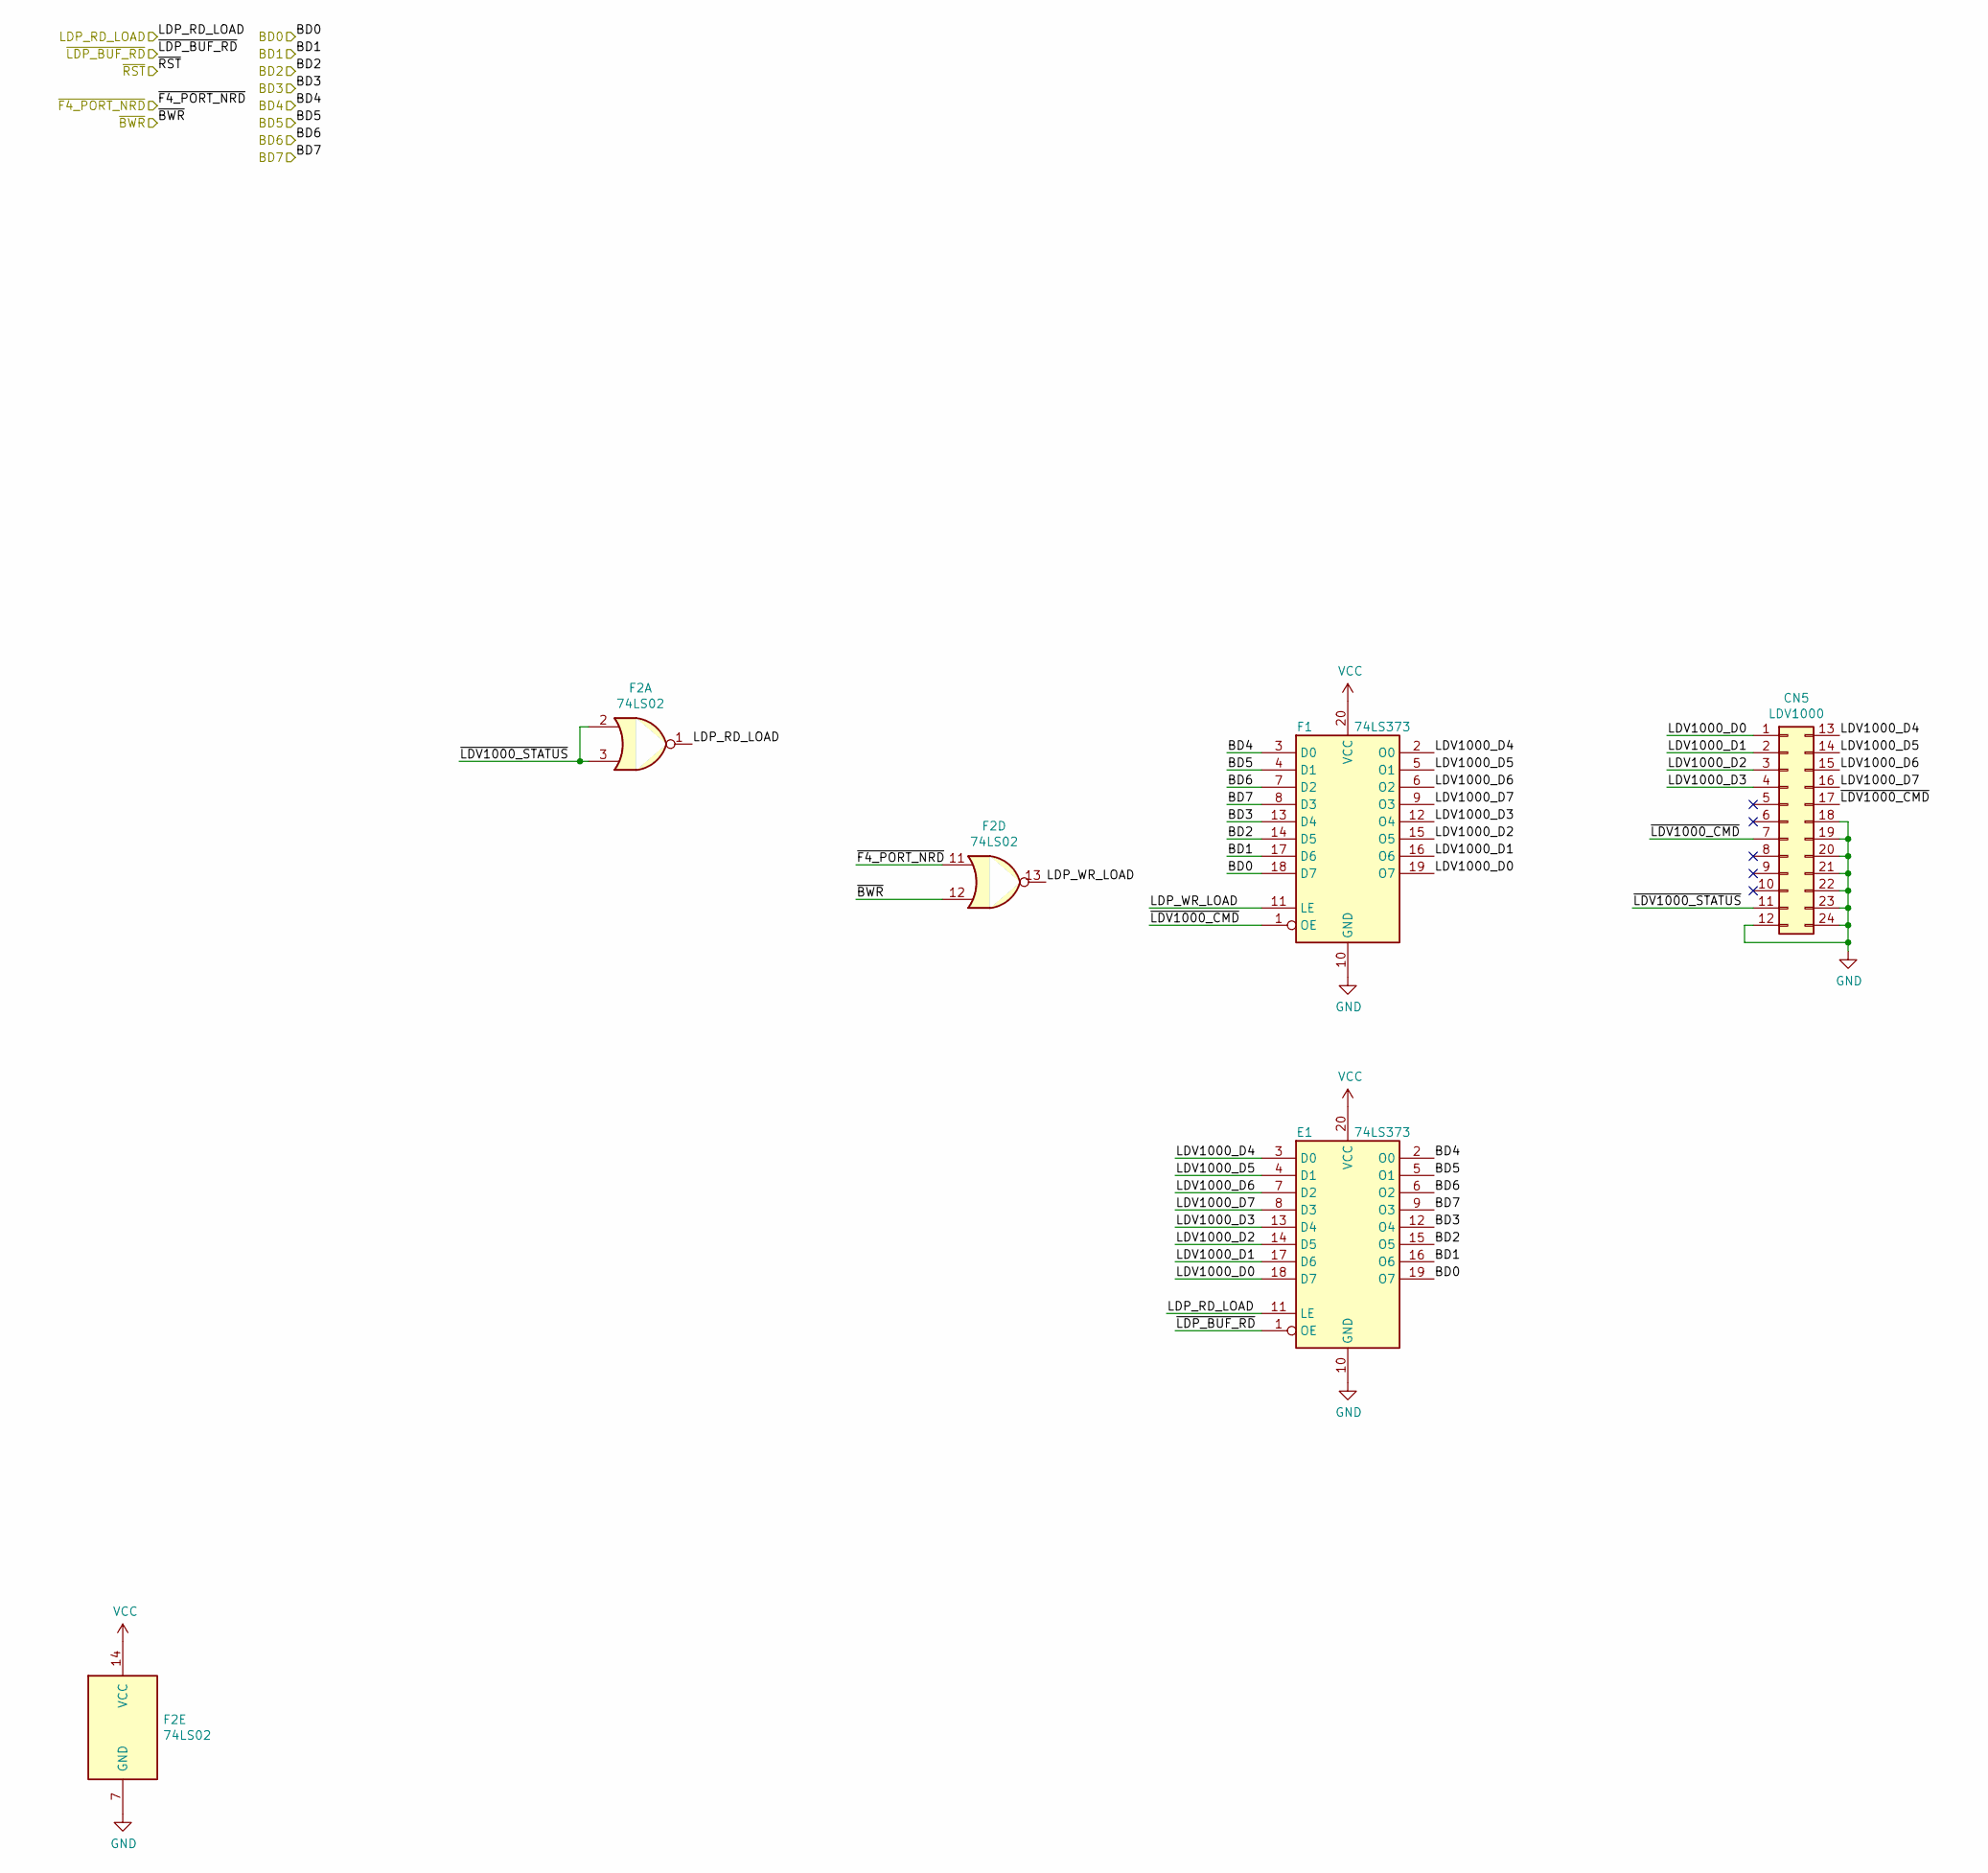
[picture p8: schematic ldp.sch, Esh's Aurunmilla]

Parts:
CN5: LDV1000; Esh_LDV1000
E1: 74LS373; DIP-20_W7.62mm_Socket
F1: 74LS373; DIP-20_W7.62mm_Socket
F2: 74LS02; DIP-14_W7.62mm_Socket

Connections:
/BD0: E1.19 (O7), F1.18 (D7); also elsewhere on the board
/BD1: E1.16 (O6), F1.17 (D6); also elsewhere on the board
/BD2: E1.15 (O5), F1.14 (D5); also elsewhere on the board
/BD3: E1.12 (O4), F1.13 (D4); also elsewhere on the board
/BD4: E1.2 (O0), F1.3 (D0); also elsewhere on the board
/BD5: E1.5 (O1), F1.4 (D1); also elsewhere on the board
/BD6: E1.6 (O2), F1.7 (D2); also elsewhere on the board
/BD7: E1.9 (O3), F1.8 (D3); also elsewhere on the board
/LDP_RD_LOAD: E1.11 (LE), F2.1; also elsewhere on the board
/ldp/LDP_WR_LOAD: F1.11 (LE), F2.13
/ldp/LDV1000_D0: CN5.1, E1.18 (D7), F1.19 (O7)
/ldp/LDV1000_D1: CN5.2, E1.17 (D6), F1.16 (O6)
/ldp/LDV1000_D2: CN5.3, E1.14 (D5), F1.15 (O5)
/ldp/LDV1000_D3: CN5.4, E1.13 (D4), F1.12 (O4)
/ldp/LDV1000_D4: CN5.13, E1.3 (D0), F1.2 (O0)
/ldp/LDV1000_D5: CN5.14, E1.4 (D1), F1.5 (O1)
/ldp/LDV1000_D6: CN5.15, E1.7 (D2), F1.6 (O2)
/ldp/LDV1000_D7: CN5.16, E1.8 (D3), F1.9 (O3)
/ldp/~LDV1000_CMD: CN5.7, CN5.17, F1.1 (OE)
/ldp/~LDV1000_STATUS: CN5.11, F2.2, F2.3
/~BWR: F2.12; also elsewhere on the board
/~F4_PORT_NRD: F2.11; also elsewhere on the board
/~LDP_BUF_RD: E1.1 (OE); also elsewhere on the board
GND: CN5.12, CN5.18, CN5.19, CN5.20, CN5.21, CN5.22, CN5.23, CN5.24, E1.10 (GND), F1.10 (GND), F2.7 (GND); also elsewhere on the board
VCC: E1.20 (VCC), F1.20 (VCC), F2.14 (VCC); also elsewhere on the board

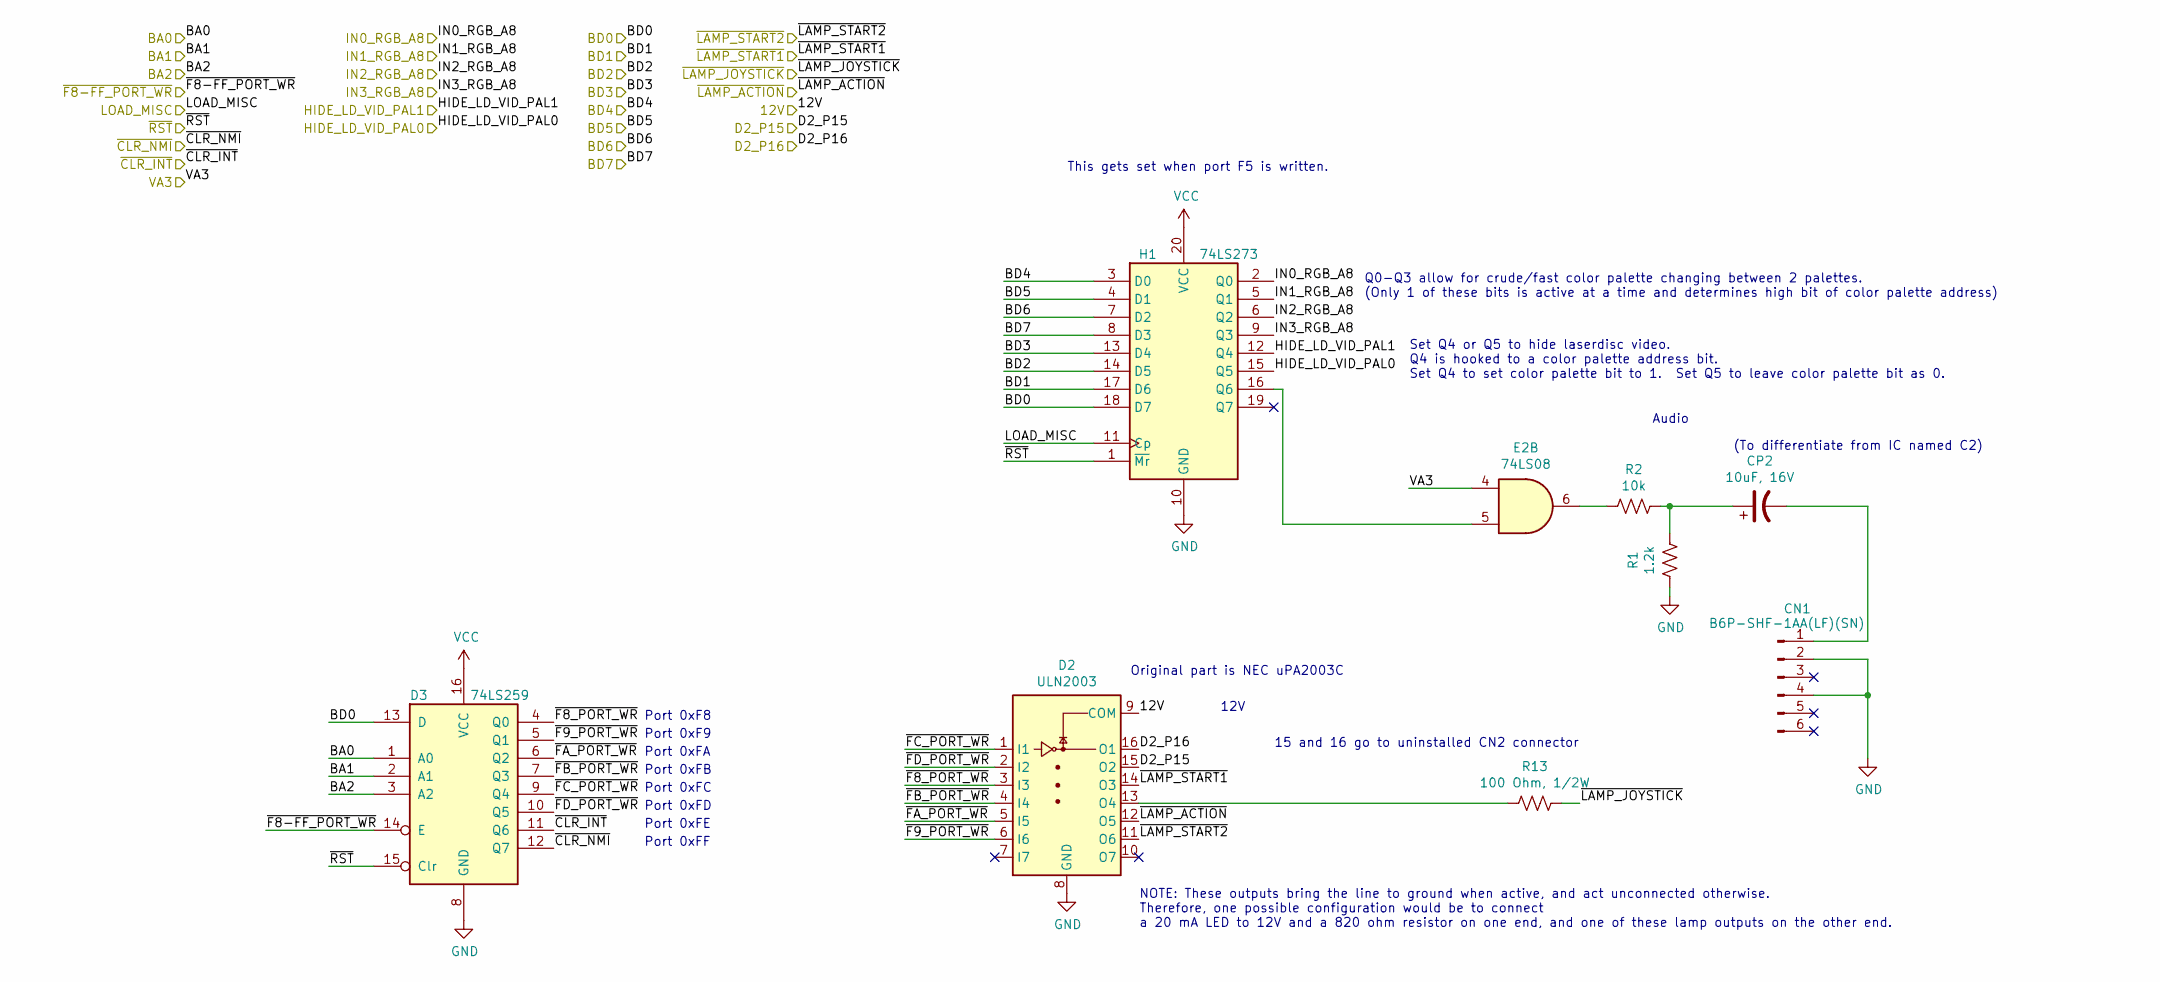
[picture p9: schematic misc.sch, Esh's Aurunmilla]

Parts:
CN1: B6P-SHF-1AA(LF)(SN); PinHeader_1x06_P2.54mm_Vertical
CP2: 10uF, 16V; CP_Radial_D5.0mm_P2.50mm
D2: ULN2003; DIP-16_W7.62mm_Socket
D3: 74LS259; DIP-16_W7.62mm_Socket
E2: 74LS08; DIP-14_W7.62mm_Socket
H1: 74LS273; DIP-20_W7.62mm_Socket
R1: 1.2k; R_Axial_DIN0207_L6.3mm_D2.5mm_P10.16mm_Horizontal
R2: 10k; R_Axial_DIN0207_L6.3mm_D2.5mm_P10.16mm_Horizontal
R13: 100 Ohm, 1/2W; R_Axial_DIN0207_L6.3mm_D2.5mm_P10.16mm_Horizontal

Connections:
/12V: D2.9 (COM); also elsewhere on the board
/BA0: D3.1 (A0); also elsewhere on the board
/BA1: D3.2 (A1); also elsewhere on the board
/BA2: D3.3 (A2); also elsewhere on the board
/BD0: D3.13 (D), H1.18 (D7); also elsewhere on the board
/BD1: H1.17 (D6); also elsewhere on the board
/BD2: H1.14 (D5); also elsewhere on the board
/BD3: H1.13 (D4); also elsewhere on the board
/BD4: H1.3 (D0); also elsewhere on the board
/BD5: H1.4 (D1); also elsewhere on the board
/BD6: H1.7 (D2); also elsewhere on the board
/BD7: H1.8 (D3); also elsewhere on the board
/D2_P15: D2.15 (O2); also elsewhere on the board
/D2_P16: D2.16 (O1); also elsewhere on the board
/HIDE_LD_VID_PAL0: H1.15 (Q5); also elsewhere on the board
/HIDE_LD_VID_PAL1: H1.12 (Q4); also elsewhere on the board
/IN0_RGB_A8: H1.2 (Q0); also elsewhere on the board
/IN1_RGB_A8: H1.5 (Q1); also elsewhere on the board
/IN2_RGB_A8: H1.6 (Q2); also elsewhere on the board
/IN3_RGB_A8: H1.9 (Q3); also elsewhere on the board
/LOAD_MISC: H1.11 (Cp); also elsewhere on the board
/VA3: E2.4; also elsewhere on the board
/misc/~F8_PORT_WR: D2.3 (I3), D3.4 (Q0)
/misc/~F9_PORT_WR: D2.6 (I6), D3.5 (Q1)
/misc/~FA_PORT_WR: D2.5 (I5), D3.6 (Q2)
/misc/~FB_PORT_WR: D2.4 (I4), D3.7 (Q3)
/misc/~FC_PORT_WR: D2.1 (I1), D3.9 (Q4)
/misc/~FD_PORT_WR: D2.2 (I2), D3.10 (Q5)
/~CLR_INT: D3.11 (Q6); also elsewhere on the board
/~CLR_NMI: D3.12 (Q7); also elsewhere on the board
/~F8-FF_PORT_WR: D3.14 (E); also elsewhere on the board
/~LAMP_ACTION: D2.12 (O5); also elsewhere on the board
/~LAMP_JOYSTICK: R13.1; also elsewhere on the board
/~LAMP_START1: D2.14 (O3); also elsewhere on the board
/~LAMP_START2: D2.11 (O6); also elsewhere on the board
/~RST: D3.15 (Clr), H1.1 (~Mr); also elsewhere on the board
GND: CN1.2, CN1.4, D2.8 (GND), D3.8 (GND), H1.10 (GND), R1.2; also elsewhere on the board
unnamed: CN1.1, CP2.2
unnamed: CP2.1, R1.1, R2.1
unnamed: D2.13 (O4), R13.2
unnamed: E2.5, H1.16 (Q6)
unnamed: E2.6, R2.2
VCC: D3.16 (VCC), H1.20 (VCC); also elsewhere on the board

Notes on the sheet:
Port 0xFF
Port 0xFE
Port 0xF8
Port 0xF9
Port 0xFA
Port 0xFB
Port 0xFC
Port 0xFD
15 and 16 go to uninstalled CN2 connector
Original part is NEC uPA2003C
12V
This gets set when port F5 is written.
Audio
(To differentiate from IC named C2)
Set Q4 or Q5 to hide laserdisc video. Q4 is hooked to a color palette address bit. Set Q4 to set color palette bit to 1. Set Q5 to leave color palette bit as 0.
Q0-Q3 allow for crude/fast color palette changing between 2 palettes. (Only 1 of these bits is active at a time and determines high bit of color palette address)
NOTE: These outputs bring the line to ground when active, and act unconnected otherwise. Therefore, one possible configuration would be to connect a 20 mA LED to 12V and a 820 ohm resistor on one end, and one of these lamp outputs on the other end.

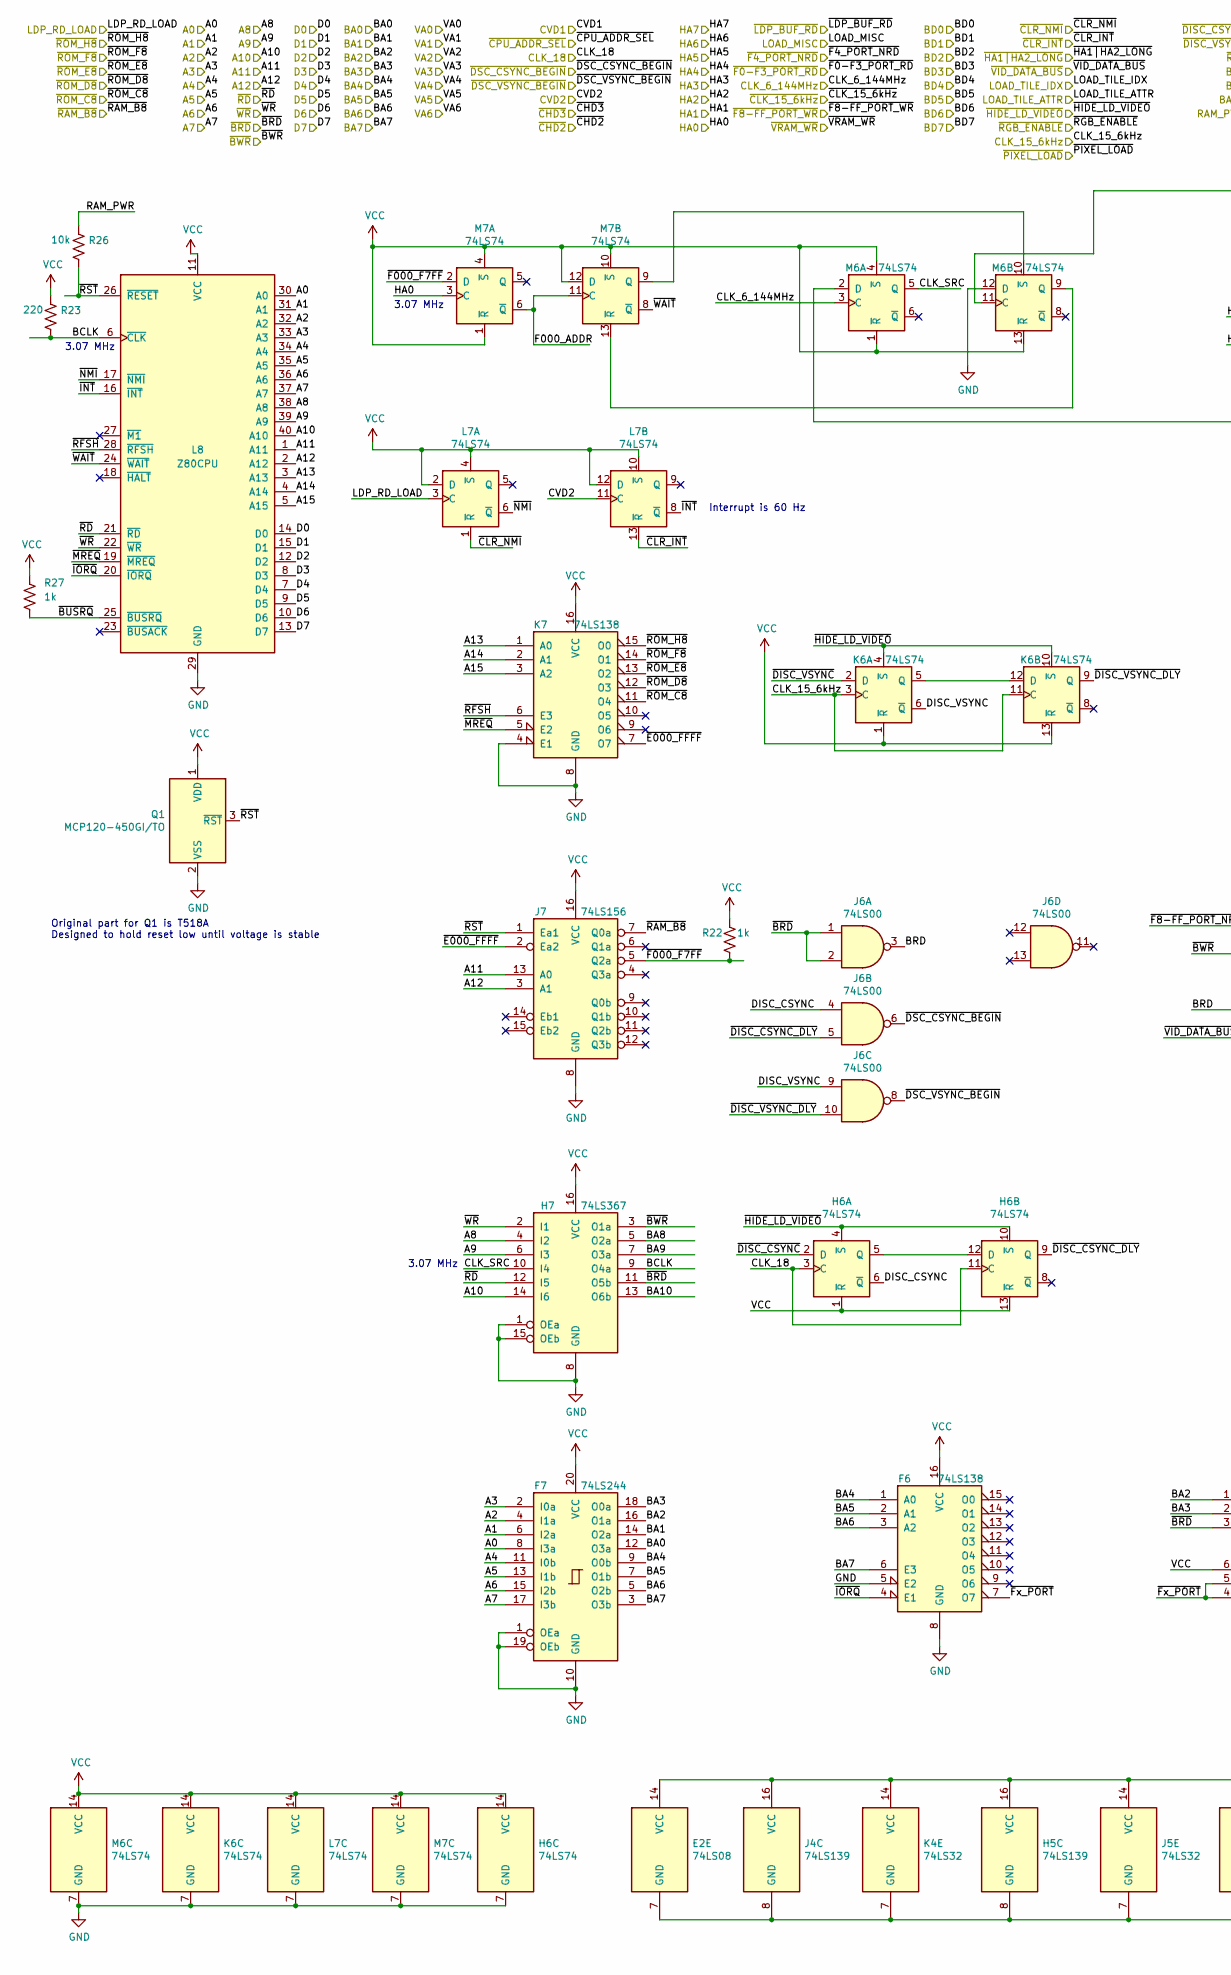
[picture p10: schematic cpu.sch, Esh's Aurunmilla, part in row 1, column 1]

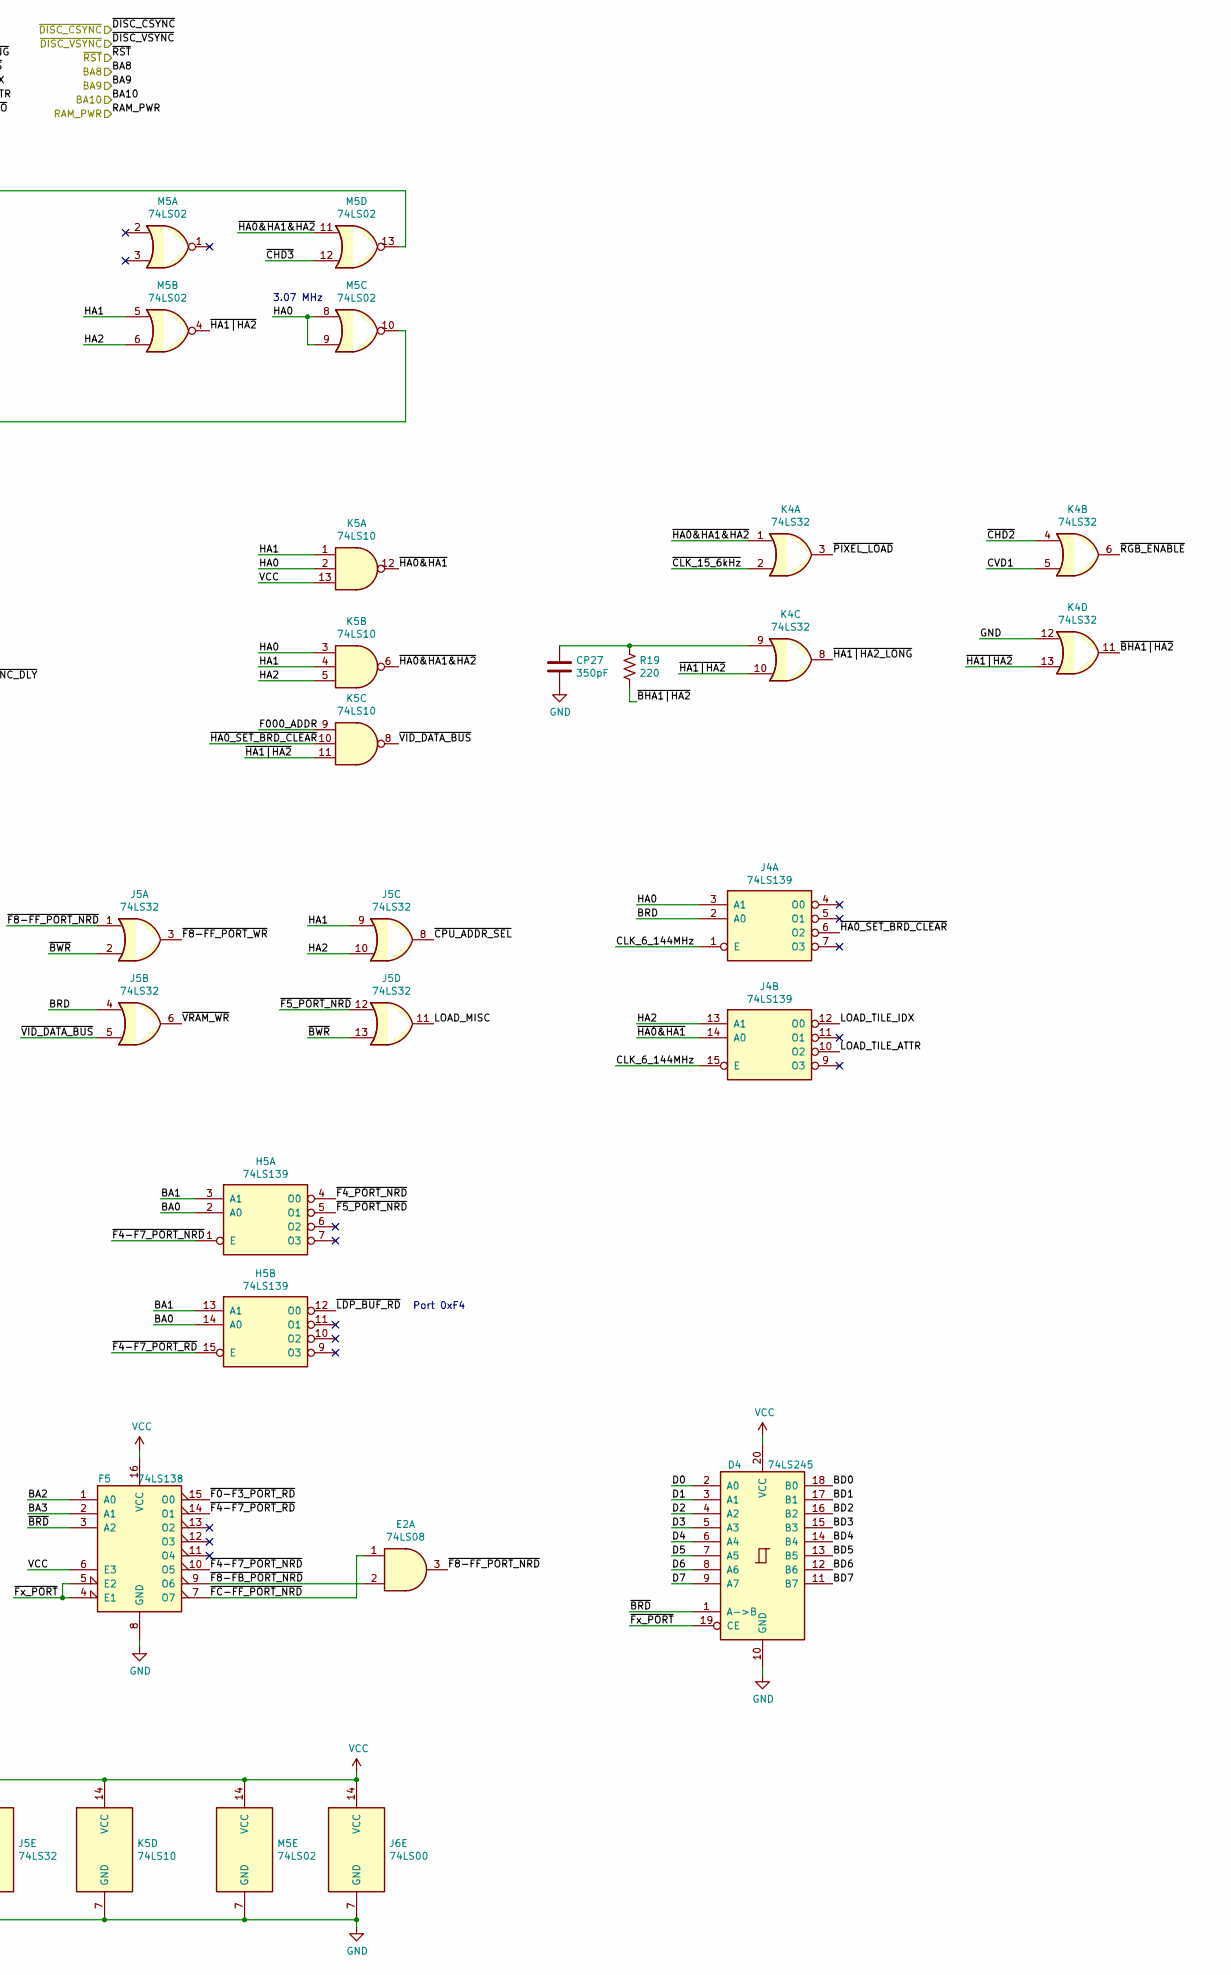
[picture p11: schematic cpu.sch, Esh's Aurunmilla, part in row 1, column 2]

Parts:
CP27: 350pF; R_Axial_DIN0204_L3.6mm_D1.6mm_P5.08mm_Horizontal
D4: 74LS245; DIP-20_W7.62mm_Socket
E2: 74LS08; DIP-14_W7.62mm_Socket
F5, F6: 74LS138; DIP-16_W7.62mm_Socket
F7: 74LS244; DIP-20_W7.62mm_Socket
H5: 74LS139; DIP-16_W7.62mm_Socket
H6: 74LS74; DIP-14_W7.62mm_Socket
H7: 74LS367; DIP-16_W7.62mm_Socket
J4: 74LS139; DIP-16_W7.62mm_Socket
J5: 74LS32; DIP-14_W7.62mm_Socket
J6: 74LS00; DIP-14_W7.62mm_Socket
J7: 74LS156; DIP-16_W7.62mm_Socket
K4: 74LS32; DIP-14_W7.62mm_Socket
K5: 74LS10; DIP-14_W7.62mm_Socket
K6: 74LS74; DIP-14_W7.62mm_Socket
K7: 74LS138; DIP-16_W7.62mm_Socket
L7: 74LS74; DIP-14_W7.62mm_Socket
L8: Z80CPU; DIP-40_W15.24mm_Socket
M5: 74LS02; DIP-14_W7.62mm_Socket
M6, M7: 74LS74; DIP-14_W7.62mm_Socket
Q1: MCP120-450GI/TO; TO-92_Inline
R19, R23: 220; R_Axial_DIN0207_L6.3mm_D2.5mm_P10.16mm_Horizontal
R22, R27: 1k; R_Axial_DIN0207_L6.3mm_D2.5mm_P10.16mm_Horizontal
R26: 10k; R_Axial_DIN0207_L6.3mm_D2.5mm_P10.16mm_Horizontal

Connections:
/A0: F7.8 (I3a), L8.30 (A0); also elsewhere on the board
/A1: F7.6 (I2a), L8.31 (A1); also elsewhere on the board
/A2: F7.4 (I1a), L8.32 (A2); also elsewhere on the board
/A3: F7.2 (I0a), L8.33 (A3); also elsewhere on the board
/A4: F7.11 (I0b), L8.34 (A4); also elsewhere on the board
/A5: F7.13 (I1b), L8.35 (A5); also elsewhere on the board
/A6: F7.15 (I2b), L8.36 (A6); also elsewhere on the board
/A7: F7.17 (I3b), L8.37 (A7); also elsewhere on the board
/A8: H7.4 (I2), L8.38 (A8); also elsewhere on the board
/A9: H7.6 (I3), L8.39 (A9); also elsewhere on the board
/A10: H7.14 (I6), L8.40 (A10); also elsewhere on the board
/A11: J7.13 (A0), L8.1 (A11); also elsewhere on the board
/A12: J7.3 (A1), L8.2 (A12); also elsewhere on the board
/BA0: F7.12 (O3a), H5.2 (A0), H5.14 (A0); also elsewhere on the board
/BA1: F7.14 (O2a), H5.3 (A1), H5.13 (A1); also elsewhere on the board
/BA2: F5.1 (A0), F7.16 (O1a); also elsewhere on the board
/BA3: F5.2 (A1), F7.18 (O0a); also elsewhere on the board
/BA4: F6.1 (A0), F7.9 (O0b); also elsewhere on the board
/BA5: F6.2 (A1), F7.7 (O1b); also elsewhere on the board
/BA6: F6.3 (A2), F7.5 (O2b); also elsewhere on the board
/BA7: F6.6 (E3), F7.3 (O3b); also elsewhere on the board
/BA8: H7.5 (O2a); also elsewhere on the board
/BA9: H7.7 (O3a); also elsewhere on the board
/BA10: H7.13 (O6b); also elsewhere on the board
/BD0: D4.18 (B0); also elsewhere on the board
/BD1: D4.17 (B1); also elsewhere on the board
/BD2: D4.16 (B2); also elsewhere on the board
/BD3: D4.15 (B3); also elsewhere on the board
/BD4: D4.14 (B4); also elsewhere on the board
/BD5: D4.13 (B5); also elsewhere on the board
/BD6: D4.12 (B6); also elsewhere on the board
/BD7: D4.11 (B7); also elsewhere on the board
/CLK_6_144MHz: J4.1 (E), J4.15 (E), M6.3 (C); also elsewhere on the board
/CLK_15_6kHz: K6.3 (C), K6.11 (C); also elsewhere on the board
/CLK_18_432MHz: H6.3 (C), H6.11 (C); also elsewhere on the board
/CVD1: K4.5; also elsewhere on the board
/CVD2: L7.11 (C); also elsewhere on the board
/D0: D4.2 (A0), L8.14 (D0); also elsewhere on the board
/D1: D4.3 (A1), L8.15 (D1); also elsewhere on the board
/D2: D4.4 (A2), L8.12 (D2); also elsewhere on the board
/D3: D4.5 (A3), L8.8 (D3); also elsewhere on the board
/D4: D4.6 (A4), L8.7 (D4); also elsewhere on the board
/D5: D4.7 (A5), L8.9 (D5); also elsewhere on the board
/D6: D4.8 (A6), L8.10 (D6); also elsewhere on the board
/D7: D4.9 (A7), L8.13 (D7); also elsewhere on the board
/HA0: J4.3 (A1), K5.2, K5.3, M5.8, M5.9, M7.3 (C); also elsewhere on the board
/HA1: J5.9, K5.1, K5.4, M5.5; also elsewhere on the board
/HA2: J4.13 (A1), J5.10, K5.5, M5.6; also elsewhere on the board
/LDP_RD_LOAD: L7.3 (C); also elsewhere on the board
/LOAD_MISC: J5.11; also elsewhere on the board
/LOAD_TILE_ATTR: J4.10 (O2); also elsewhere on the board
/LOAD_TILE_IDX: J4.12 (O0); also elsewhere on the board
/RAM_PWR: R26.1; also elsewhere on the board
/cpu/A13: K7.1 (A0), L8.3 (A13)
/cpu/A14: K7.2 (A1), L8.4 (A14)
/cpu/A15: K7.3 (A2), L8.5 (A15)
/cpu/BCLK: H7.9 (O4a), L8.6 (~CLK~), R23.2
/cpu/BRD: J4.2 (A0), J5.4, J6.3
/cpu/CLK_SRC: H7.10 (I4), M6.5 (Q)
/cpu/DISC_CSYNC: H6.6 (~Q), J6.4
/cpu/DISC_VSYNC: J6.9, K6.6 (~Q)
/cpu/F000_ADDR: K5.9, M7.6 (~Q), M7.11 (C)
/cpu/~BHA1|HA2: K4.11, R19.2
/cpu/~BUSRQ: L8.25 (~BUSRQ~), R27.2
/cpu/~DISC_CSYNC_DLY: H6.9 (Q), J6.5
/cpu/~DISC_VSYNC_DLY: J6.10, K6.9 (Q)
/cpu/~E000_FFFF: J7.2 (Ea2), K7.7 (O7)
/cpu/~F000_F7FF: J7.5 (Q2a), M7.2 (D), R22.2
/cpu/~F4-F7_PORT_NRD: F5.10 (O5), H5.1 (E)
/cpu/~F4-F7_PORT_RD: F5.14 (O1), H5.15 (E)
/cpu/~F5_PORT_NRD: H5.5 (O1), J5.12
/cpu/~F8-FB_PORT_NRD: E2.2, F5.9 (O6)
/cpu/~F8-FF_PORT_NRD: E2.3, J5.1
/cpu/~FC-FF_PORT_NRD: E2.1, F5.7 (O7)
/cpu/~Fx_PORT: D4.19 (CE), F5.4 (E1), F5.5 (E2), F6.7 (O7)
/cpu/~HA0&HA1: J4.14 (A0), K5.12
/cpu/~HA0&HA1&HA2: K4.1, K5.6, M5.11
/cpu/~HA0_SET_BRD_CLEAR: J4.6 (O2), K5.10
/cpu/~HA1|HA2: K4.10, K4.13, K5.11, M5.4
/cpu/~INT: L7.8 (~Q), L8.16 (~INT~)
/cpu/~IORQ: F6.4 (E1), L8.20 (~IORQ~)
/cpu/~MREQ: K7.5 (E2), L8.19 (~MREQ~)
/cpu/~NMI: L7.6 (~Q), L8.17 (~NMI~)
/cpu/~RFSH: K7.6 (E3), L8.28 (~RFSH~)
/cpu/~WAIT: L8.24 (~WAIT~), M7.8 (~Q)
/~BRD: D4.1 (A->B), F5.3 (A2), H7.11 (O5b), J6.1, J6.2; also elsewhere on the board
/~BWR: H7.3 (O1a), J5.2, J5.13; also elsewhere on the board
/~CHD2: K4.4; also elsewhere on the board
/~CHD3: M5.12; also elsewhere on the board
/~CLK_15_6kHz: K4.2; also elsewhere on the board
/~CLR_INT: L7.13 (~R); also elsewhere on the board
/~CLR_NMI: L7.1 (~R); also elsewhere on the board
/~CPU_ADDR_SEL: J5.8; also elsewhere on the board
/~DISC_CSYNC: H6.2 (D); also elsewhere on the board
/~DISC_VSYNC: K6.2 (D); also elsewhere on the board
/~DSC_CSYNC_BEGIN: J6.6; also elsewhere on the board
/~DSC_VSYNC_BEGIN: J6.8; also elsewhere on the board
/~F0-F3_PORT_RD: F5.15 (O0); also elsewhere on the board
/~F4_PORT_NRD: H5.4 (O0); also elsewhere on the board
/~F8-FF_PORT_WR: J5.3; also elsewhere on the board
/~HA1|HA2_LONG: K4.8; also elsewhere on the board
/~HIDE_LD_VIDEO: H6.4 (~S), H6.10 (~S), K6.4 (~S), K6.10 (~S); also elsewhere on the board
/~LDP_BUF_RD: H5.12 (O0); also elsewhere on the board
/~PIXEL_LOAD: K4.3; also elsewhere on the board
/~RAM_B8: J7.7 (Q0a); also elsewhere on the board
/~RD: H7.12 (I5), L8.21 (~RD~); also elsewhere on the board
/~RGB_ENABLE: K4.6; also elsewhere on the board
/~ROM_C8: K7.11 (O4); also elsewhere on the board
/~ROM_D8: K7.12 (O3); also elsewhere on the board
/~ROM_E8: K7.13 (O2); also elsewhere on the board
/~ROM_F8: K7.14 (O1); also elsewhere on the board
/~ROM_H8: K7.15 (O0); also elsewhere on the board
/~RST: J7.1 (Ea1), L8.26 (~RESET~), Q1.3 (~RST), R26.2; also elsewhere on the board
/~VID_DATA_BUS: J5.5, K5.8; also elsewhere on the board
/~VRAM_WR: J5.6; also elsewhere on the board
/~WR: H7.2 (I1), L8.22 (~WR~); also elsewhere on the board
GND: CP27.2, D4.10 (GND), E2.7 (GND), F5.8 (GND), F6.5 (E2), F6.8 (GND), F7.1 (OEa), F7.10 (GND), F7.19 (OEb), H5.8 (GND), H6.7 (GND), H7.1 (OEa), H7.8 (GND), H7.15 (OEb), J4.8 (GND), J5.7 (GND), J6.7 (GND), J7.8 (GND), K4.7 (GND), K4.12, K5.7 (GND), K6.7 (GND), K7.4 (E1), K7.8 (GND), L7.7 (GND), L8.29 (GND), M5.7 (GND), M6.7 (GND), M6.12 (D), M7.7 (GND), Q1.2 (VSS); also elsewhere on the board
unnamed: CP27.1, K4.9, R19.1
unnamed: H6.5 (Q), H6.12 (D)
unnamed: K6.5 (Q), K6.12 (D)
unnamed: M5.10, M6.2 (D)
unnamed: M5.13, M6.11 (C)
unnamed: M6.9 (Q), M7.13 (~R)
unnamed: M6.10 (~S), M7.9 (Q)
VCC: D4.20 (VCC), E2.14 (VCC), F5.6 (E3), F5.16 (VCC), F6.16 (VCC), F7.20 (VCC), H5.16 (VCC), H6.1 (~R), H6.13 (~R), H6.14 (VCC), H7.16 (VCC), J4.16 (VCC), J5.14 (VCC), J6.14 (VCC), J7.16 (VCC), K4.14 (VCC), K5.13, K5.14 (VCC), K6.1 (~R), K6.13 (~R), K6.14 (VCC), K7.16 (VCC), L7.2 (D), L7.4 (~S), L7.10 (~S), L7.12 (D), L7.14 (VCC), L8.11 (VCC), M5.14 (VCC), M6.1 (~R), M6.4 (~S), M6.13 (~R), M6.14 (VCC), M7.1 (~R), M7.4 (~S), M7.10 (~S), M7.12 (D), M7.14 (VCC), Q1.1 (VDD), R22.1, R23.1, R27.1; also elsewhere on the board

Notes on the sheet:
Original part for Q1 is T518A Designed to hold reset low until voltage is stable
3.07 MHz
Port 0xF4
Interrupt is 60 Hz

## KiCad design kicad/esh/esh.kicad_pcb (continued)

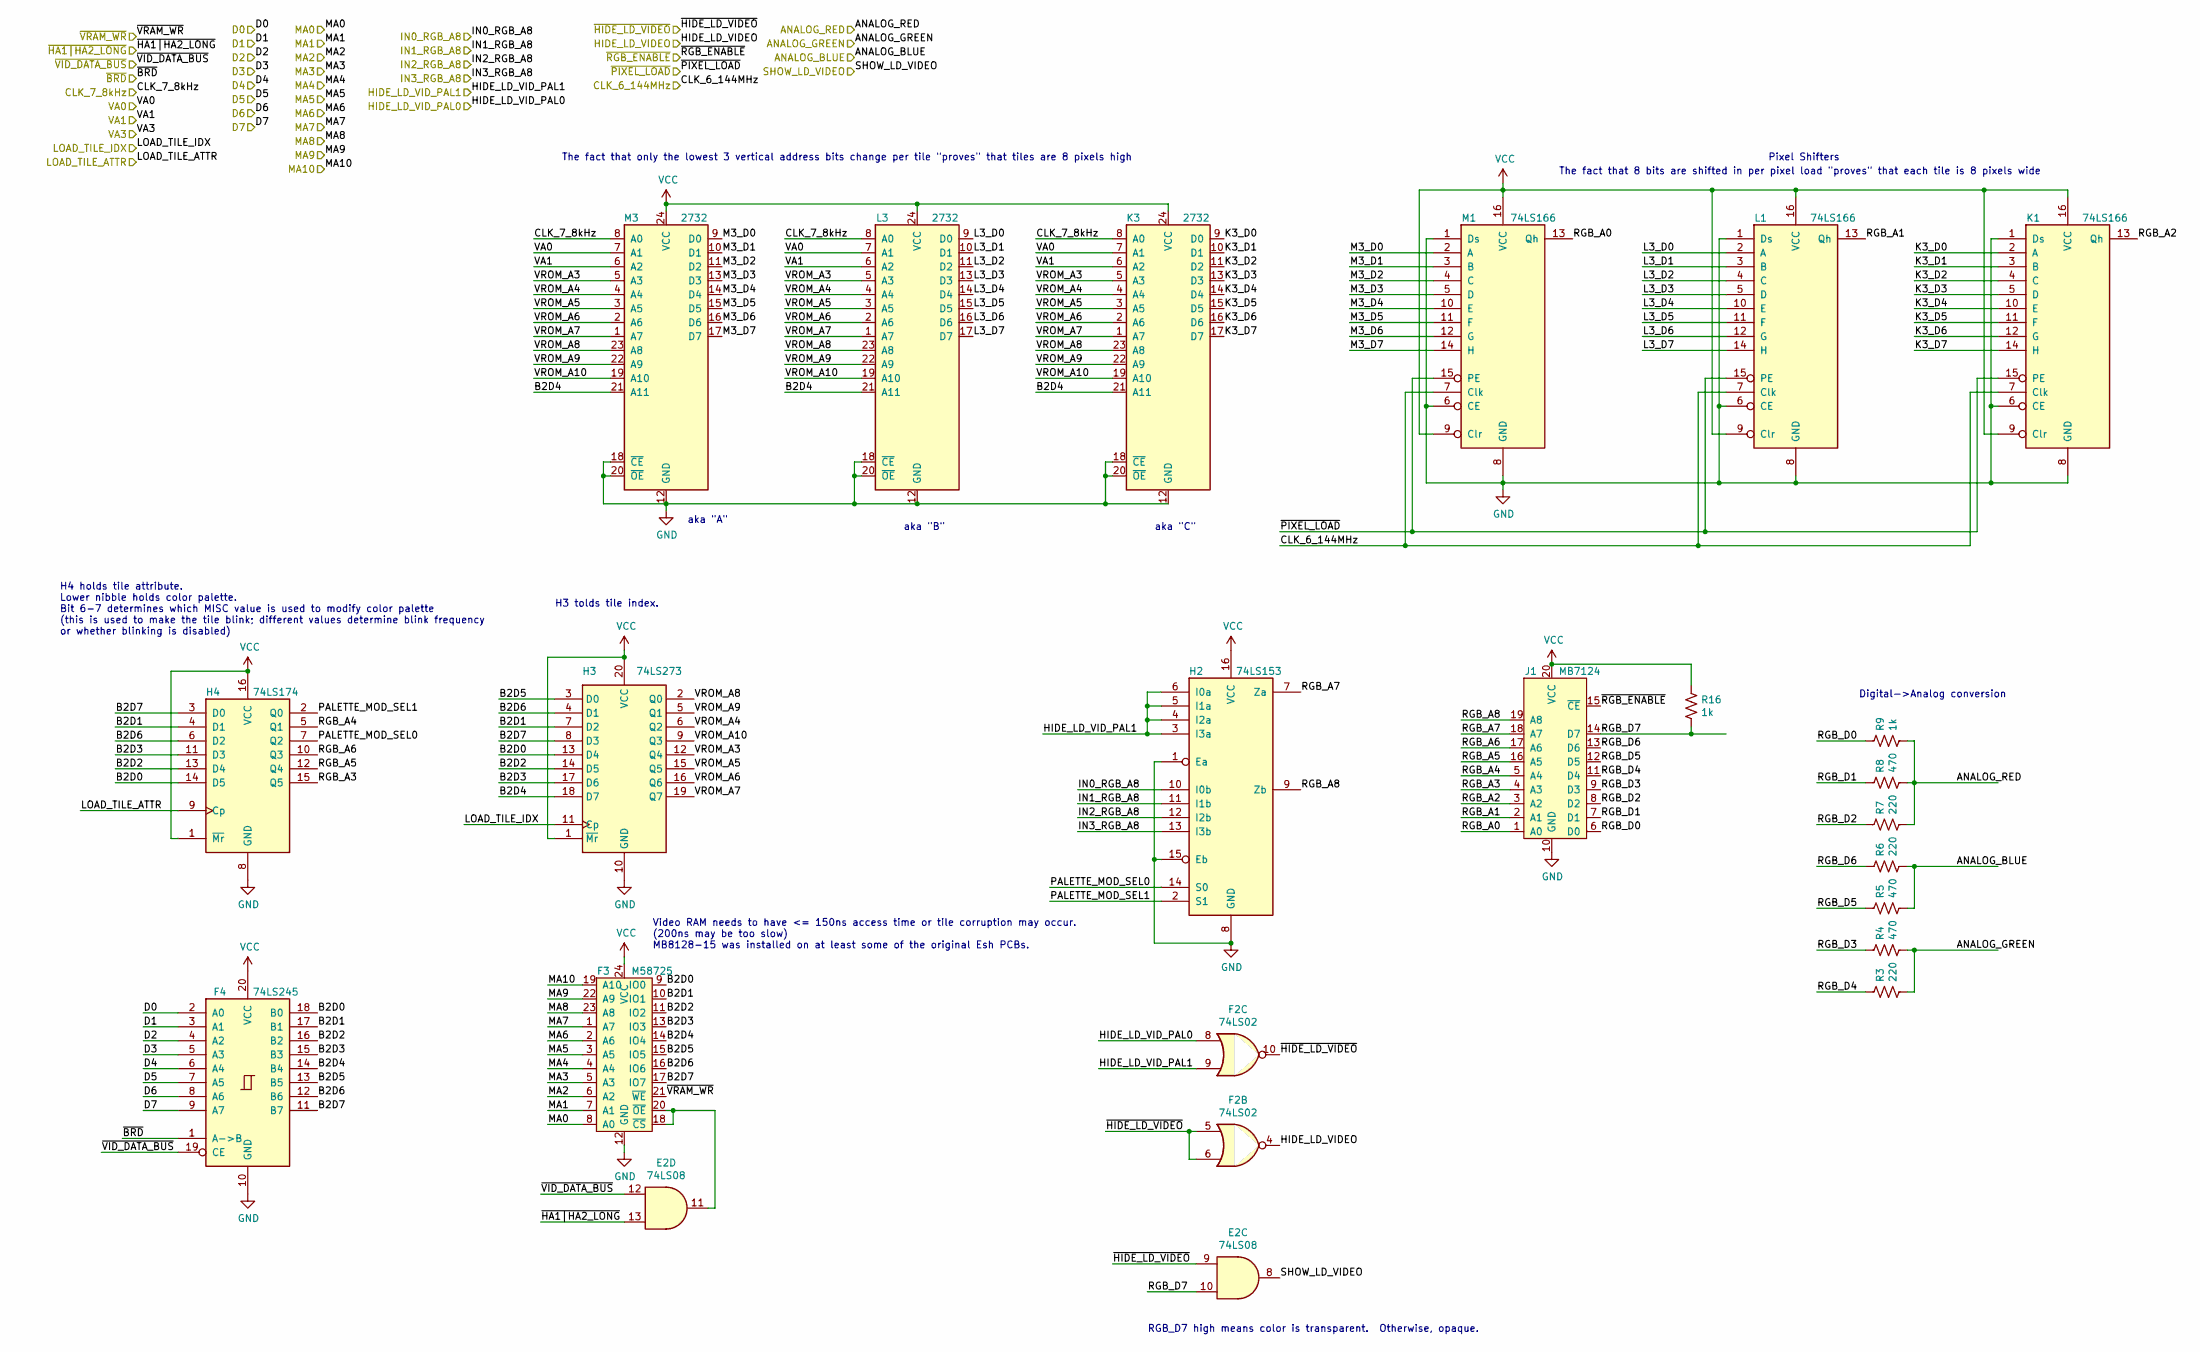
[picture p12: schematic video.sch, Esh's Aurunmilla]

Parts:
E2: 74LS08; DIP-14_W7.62mm_Socket
F2: 74LS02; DIP-14_W7.62mm_Socket
F3: M58725; DIP-24_W15.24mm_Socket
F4: 74LS245; DIP-20_W7.62mm_Socket
H2: 74LS153; DIP-16_W7.62mm_Socket
H3: 74LS273; DIP-20_W7.62mm_Socket
H4: 74LS174; DIP-16_W7.62mm_Socket
J1: MB7124; DIP-20_W7.62mm_Socket
K1: 74LS166; DIP-16_W7.62mm_Socket
K3: 2732; DIP-24_W15.24mm_Socket
L1: 74LS166; DIP-16_W7.62mm_Socket
L3: 2732; DIP-24_W15.24mm_Socket
M1: 74LS166; DIP-16_W7.62mm_Socket
M3: 2732; DIP-24_W15.24mm_Socket
R3, R6, R7: 220; R_Axial_DIN0207_L6.3mm_D2.5mm_P10.16mm_Horizontal
R4, R5, R8: 470; R_Axial_DIN0207_L6.3mm_D2.5mm_P10.16mm_Horizontal
R9, R16: 1k; R_Axial_DIN0207_L6.3mm_D2.5mm_P10.16mm_Horizontal

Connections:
/ANALOG_BLUE: R5.2, R6.2; also elsewhere on the board
/ANALOG_GREEN: R3.2, R4.2; also elsewhere on the board
/ANALOG_RED: R7.2, R8.2, R9.2; also elsewhere on the board
/CLK_6_144MHz: K1.7 (Clk), L1.7 (Clk), M1.7 (Clk); also elsewhere on the board
/CLK_7_8kHz: K3.8 (A0), L3.8 (A0), M3.8 (A0); also elsewhere on the board
/D0: F4.2 (A0); also elsewhere on the board
/D1: F4.3 (A1); also elsewhere on the board
/D2: F4.4 (A2); also elsewhere on the board
/D3: F4.5 (A3); also elsewhere on the board
/D4: F4.6 (A4); also elsewhere on the board
/D5: F4.7 (A5); also elsewhere on the board
/D6: F4.8 (A6); also elsewhere on the board
/D7: F4.9 (A7); also elsewhere on the board
/HIDE_LD_VIDEO: F2.4; also elsewhere on the board
/HIDE_LD_VID_PAL0: F2.8; also elsewhere on the board
/HIDE_LD_VID_PAL1: F2.9, H2.3 (I3a), H2.4 (I2a), H2.5 (I1a), H2.6 (I0a); also elsewhere on the board
/IN0_RGB_A8: H2.10 (I0b); also elsewhere on the board
/IN1_RGB_A8: H2.11 (I1b); also elsewhere on the board
/IN2_RGB_A8: H2.12 (I2b); also elsewhere on the board
/IN3_RGB_A8: H2.13 (I3b); also elsewhere on the board
/LOAD_TILE_ATTR: H4.9 (Cp); also elsewhere on the board
/LOAD_TILE_IDX: H3.11 (Cp); also elsewhere on the board
/MA0: F3.8 (A0); also elsewhere on the board
/MA1: F3.7 (A1); also elsewhere on the board
/MA2: F3.6 (A2); also elsewhere on the board
/MA3: F3.5 (A3); also elsewhere on the board
/MA4: F3.4 (A4); also elsewhere on the board
/MA5: F3.3 (A5); also elsewhere on the board
/MA6: F3.2 (A6); also elsewhere on the board
/MA7: F3.1 (A7); also elsewhere on the board
/MA8: F3.23 (A8); also elsewhere on the board
/MA9: F3.22 (A9); also elsewhere on the board
/MA10: F3.19 (A10); also elsewhere on the board
/SHOW_LD_VIDEO: E2.8; also elsewhere on the board
/VA0: K3.7 (A1), L3.7 (A1), M3.7 (A1); also elsewhere on the board
/VA1: K3.6 (A2), L3.6 (A2), M3.6 (A2); also elsewhere on the board
/video/B2D0: F3.9 (IO0), F4.18 (B0), H3.13 (D4), H4.14 (D5)
/video/B2D1: F3.10 (IO1), F4.17 (B1), H3.7 (D2), H4.4 (D1)
/video/B2D2: F3.11 (IO2), F4.16 (B2), H3.14 (D5), H4.13 (D4)
/video/B2D3: F3.13 (IO3), F4.15 (B3), H3.17 (D6), H4.11 (D3)
/video/B2D4: F3.14 (IO4), F4.14 (B4), H3.18 (D7), K3.21 (A11), L3.21 (A11), M3.21 (A11)
/video/B2D5: F3.15 (IO5), F4.13 (B5), H3.3 (D0)
/video/B2D6: F3.16 (IO6), F4.12 (B6), H3.4 (D1), H4.6 (D2)
/video/B2D7: F3.17 (IO7), F4.11 (B7), H3.8 (D3), H4.3 (D0)
/video/K3_D0: K1.2 (A), K3.9 (D0)
/video/K3_D1: K1.3 (B), K3.10 (D1)
/video/K3_D2: K1.4 (C), K3.11 (D2)
/video/K3_D3: K1.5 (D), K3.13 (D3)
/video/K3_D4: K1.10 (E), K3.14 (D4)
/video/K3_D5: K1.11 (F), K3.15 (D5)
/video/K3_D6: K1.12 (G), K3.16 (D6)
/video/K3_D7: K1.14 (H), K3.17 (D7)
/video/L3_D0: L1.2 (A), L3.9 (D0)
/video/L3_D1: L1.3 (B), L3.10 (D1)
/video/L3_D2: L1.4 (C), L3.11 (D2)
/video/L3_D3: L1.5 (D), L3.13 (D3)
/video/L3_D4: L1.10 (E), L3.14 (D4)
/video/L3_D5: L1.11 (F), L3.15 (D5)
/video/L3_D6: L1.12 (G), L3.16 (D6)
/video/L3_D7: L1.14 (H), L3.17 (D7)
/video/M3_D0: M1.2 (A), M3.9 (D0)
/video/M3_D1: M1.3 (B), M3.10 (D1)
/video/M3_D2: M1.4 (C), M3.11 (D2)
/video/M3_D3: M1.5 (D), M3.13 (D3)
/video/M3_D4: M1.10 (E), M3.14 (D4)
/video/M3_D5: M1.11 (F), M3.15 (D5)
/video/M3_D6: M1.12 (G), M3.16 (D6)
/video/M3_D7: M1.14 (H), M3.17 (D7)
/video/PALETTE_MOD_SEL0: H2.14 (S0), H4.7 (Q2)
/video/PALETTE_MOD_SEL1: H2.2 (S1), H4.2 (Q0)
/video/RGB_A0: J1.1 (A0), M1.13 (Qh)
/video/RGB_A1: J1.2 (A1), L1.13 (Qh)
/video/RGB_A2: J1.3 (A2), K1.13 (Qh)
/video/RGB_A3: H4.15 (Q5), J1.4 (A3)
/video/RGB_A4: H4.5 (Q1), J1.5 (A4)
/video/RGB_A5: H4.12 (Q4), J1.16 (A5)
/video/RGB_A6: H4.10 (Q3), J1.17 (A6)
/video/RGB_A7: H2.7 (Za), J1.18 (A7)
/video/RGB_A8: H2.9 (Zb), J1.19 (A8)
/video/RGB_D0: J1.6 (D0), R9.1
/video/RGB_D1: J1.7 (D1), R8.1
/video/RGB_D2: J1.8 (D2), R7.1
/video/RGB_D3: J1.9 (D3), R4.1
/video/RGB_D4: J1.11 (D4), R3.1
/video/RGB_D5: J1.12 (D5), R5.1
/video/RGB_D6: J1.13 (D6), R6.1
/video/RGB_D7: E2.10, J1.14 (D7), R16.2
/video/VROM_A3: H3.12 (Q4), K3.5 (A3), L3.5 (A3), M3.5 (A3)
/video/VROM_A4: H3.6 (Q2), K3.4 (A4), L3.4 (A4), M3.4 (A4)
/video/VROM_A5: H3.15 (Q5), K3.3 (A5), L3.3 (A5), M3.3 (A5)
/video/VROM_A6: H3.16 (Q6), K3.2 (A6), L3.2 (A6), M3.2 (A6)
/video/VROM_A7: H3.19 (Q7), K3.1 (A7), L3.1 (A7), M3.1 (A7)
/video/VROM_A8: H3.2 (Q0), K3.23 (A8), L3.23 (A8), M3.23 (A8)
/video/VROM_A9: H3.5 (Q1), K3.22 (A9), L3.22 (A9), M3.22 (A9)
/video/VROM_A10: H3.9 (Q3), K3.19 (A10), L3.19 (A10), M3.19 (A10)
/~BRD: F4.1 (A->B); also elsewhere on the board
/~HA1|HA2_LONG: E2.13; also elsewhere on the board
/~HIDE_LD_VIDEO: E2.9, F2.5, F2.6, F2.10; also elsewhere on the board
/~PIXEL_LOAD: K1.15 (PE), L1.15 (PE), M1.15 (PE); also elsewhere on the board
/~RGB_ENABLE: J1.15 (~CE); also elsewhere on the board
/~VID_DATA_BUS: E2.12, F4.19 (CE); also elsewhere on the board
/~VRAM_WR: F3.21 (~WE); also elsewhere on the board
GND: F3.12 (GND), F4.10 (GND), H2.1 (Ea), H2.8 (GND), H2.15 (Eb), H3.10 (GND), H4.8 (GND), J1.10 (GND), K1.1 (Ds), K1.6 (CE), K1.8 (GND), K3.12 (GND), K3.18 (~CE), K3.20 (~OE), L1.1 (Ds), L1.6 (CE), L1.8 (GND), L3.12 (GND), L3.18 (~CE), L3.20 (~OE), M1.1 (Ds), M1.6 (CE), M1.8 (GND), M3.12 (GND), M3.18 (~CE), M3.20 (~OE); also elsewhere on the board
unnamed: E2.11, F3.18 (~CS), F3.20 (~OE)
VCC: F3.24 (VCC), F4.20 (VCC), H2.16 (VCC), H3.1 (~Mr), H3.20 (VCC), H4.1 (~Mr), H4.16 (VCC), J1.20 (VCC), K1.9 (Clr), K1.16 (VCC), K3.24 (VCC), L1.9 (Clr), L1.16 (VCC), L3.24 (VCC), M1.9 (Clr), M1.16 (VCC), M3.24 (VCC), R16.1; also elsewhere on the board

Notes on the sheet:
RGB_D7 high means color is transparent. Otherwise, opaque.
aka "A"
aka "B"
aka "C"
Pixel Shifters
H4 holds tile attribute. Lower nibble holds color palette. Bit 6-7 determines which MISC value is used to modify color palette (this is used to make the tile blink; different values determine blink frequency or whether blinking is disabled)
H3 tolds tile index.
The fact that only the lowest 3 vertical address bits change per tile "proves" that tiles are 8 pixels high
The fact that 8 bits are shifted in per pixel load "proves" that each tile is 8 pixels wide
Digital->Analog conversion
Video RAM needs to have <= 150ns access time or tile corruption may occur. (200ns may be too slow) MB8128-15 was installed on at least some of the original Esh PCBs.


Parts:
E5, E6, E7: 74LS157; DIP-16_W7.62mm_Socket

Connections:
/BA0: E5.2 (I0a); also elsewhere on the board
/BA1: E5.5 (I0b); also elsewhere on the board
/BA2: E5.11 (I0c); also elsewhere on the board
/BA3: E5.14 (I0d); also elsewhere on the board
/BA4: E6.2 (I0a); also elsewhere on the board
/BA5: E6.5 (I0b); also elsewhere on the board
/BA6: E6.11 (I0c); also elsewhere on the board
/BA7: E6.14 (I0d); also elsewhere on the board
/BA8: E7.2 (I0a); also elsewhere on the board
/BA9: E7.5 (I0b); also elsewhere on the board
/BA10: E7.11 (I0c); also elsewhere on the board
/HA2: E7.10 (I1c); also elsewhere on the board
/HA3: E5.3 (I1a); also elsewhere on the board
/HA4: E5.6 (I1b); also elsewhere on the board
/HA5: E5.10 (I1c); also elsewhere on the board
/HA6: E5.13 (I1d); also elsewhere on the board
/HA7: E6.3 (I1a); also elsewhere on the board
/MA0: E5.4 (Za); also elsewhere on the board
/MA1: E5.7 (Zb); also elsewhere on the board
/MA2: E5.9 (Zc); also elsewhere on the board
/MA3: E5.12 (Zd); also elsewhere on the board
/MA4: E6.4 (Za); also elsewhere on the board
/MA5: E6.7 (Zb); also elsewhere on the board
/MA6: E6.9 (Zc); also elsewhere on the board
/MA7: E6.12 (Zd); also elsewhere on the board
/MA8: E7.4 (Za); also elsewhere on the board
/MA9: E7.7 (Zb); also elsewhere on the board
/MA10: E7.9 (Zc); also elsewhere on the board
/VA2: E6.6 (I1b); also elsewhere on the board
/VA3: E6.10 (I1c); also elsewhere on the board
/VA4: E6.13 (I1d); also elsewhere on the board
/VA5: E7.3 (I1a); also elsewhere on the board
/VA6: E7.6 (I1b); also elsewhere on the board
/~CPU_ADDR_SEL: E5.1 (S), E6.1 (S), E7.1 (S); also elsewhere on the board
GND: E5.8 (GND), E5.15 (E), E6.8 (GND), E6.15 (E), E7.8 (GND), E7.15 (E); also elsewhere on the board
VCC: E5.16 (VCC), E6.16 (VCC), E7.16 (VCC); also elsewhere on the board

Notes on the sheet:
So CPU can modify video RAM, while also allowing computer-generated video to be constantly redrawn

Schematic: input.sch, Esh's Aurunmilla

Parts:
A2: 74LS253; DIP-16_W7.62mm_Socket
B2: 74LS253; DIP-16_W7.62mm_Socket
C2: 74LS253; DIP-16_W7.62mm_Socket
INP_C3, INP_C4, INP_C7, INP_C11, INP_C12, INP_C13, INP_C17, INP_C18, INP_C19, INP_C21, INP_C22, INP_C23, INP_C24, INP_C25: 0.1uF; R_Axial_DIN0204_L3.6mm_D1.6mm_P5.08mm_Horizontal
RA1, RA2, RA3: 1k; R_Array_SIP9
RA4, RA5, RA6, RA7, RA8, RA9: 220; R_Array_SIP8

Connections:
/BA0: A2.14 (A0), B2.14 (A0), C2.14 (A0); also elsewhere on the board
/BA1: A2.2 (A1), B2.2 (A1), C2.2 (A1); also elsewhere on the board
/BD0: C2.7 (Za); also elsewhere on the board
/BD1: C2.9 (Zb); also elsewhere on the board
/BD2: B2.7 (Za); also elsewhere on the board
/BD3: B2.9 (Zb); also elsewhere on the board
/BD4: A2.7 (Za); also elsewhere on the board
/BD5: A2.9 (Zb); also elsewhere on the board
/RA1_P5: RA1.5 (R4), RA4.4 (R2.2); also elsewhere on the board
/RA1_P9: RA1.9 (R8), RA4.8 (R4.2); also elsewhere on the board
/RA2_P4: RA2.4 (R3), RA5.4 (R2.2); also elsewhere on the board
/RA2_P7: RA2.7 (R6), RA8.6 (R3.2); also elsewhere on the board
/RA3_P3: RA3.3 (R2), RA6.2 (R1.2); also elsewhere on the board
/RA3_P8: RA3.8 (R7), RA6.8 (R4.2); also elsewhere on the board
/input/A2_P3: A2.3 (I3a), RA7.3 (R2.1)
/input/A2_P4: A2.4 (I2a), RA4.3 (R2.1)
/input/A2_P10: A2.10 (I0b), RA4.5 (R3.1)
/input/A2_P12: A2.12 (I2b), RA4.7 (R4.1)
/input/A2_P13: A2.13 (I3b), RA7.7 (R4.1)
/input/B2_P4: B2.4 (I2a), RA5.3 (R2.1)
/input/B2_P12: B2.12 (I2b), RA8.5 (R3.1)
/input/B2_P13: B2.13 (I3b), RA5.5 (R3.1)
/input/C2_P4: C2.4 (I2a), RA6.1 (R1.1)
/input/C2_P12: C2.12 (I2b), RA6.7 (R4.1)
/input/~DBNC_ACTION: A2.5 (I1a), INP_C3.1, RA7.1 (R1.1)
/input/~DBNC_ACTION2: A2.11 (I1b), INP_C7.1, RA7.5 (R3.1)
/input/~DBNC_COIN1: C2.6 (I0a), INP_C19.1, RA9.1 (R1.1)
/input/~DBNC_COIN2: C2.10 (I0b), INP_C23.1, RA9.5 (R3.1)
/input/~DBNC_DOWN: C2.11 (I1b), INP_C24.1, RA6.5 (R3.1)
/input/~DBNC_LEFT: B2.5 (I1a), INP_C12.1, RA5.1 (R1.1)
/input/~DBNC_RIGHT: B2.11 (I1b), INP_C18.1, RA5.7 (R4.1)
/input/~DBNC_START1: B2.6 (I0a), INP_C11.1, RA8.1 (R1.1)
/input/~DBNC_START2: B2.10 (I0b), INP_C17.1, RA8.7 (R4.1)
/input/~DBNC_TEST: A2.6 (I0a), INP_C4.1, RA4.1 (R1.1)
/input/~DBNC_UNK1: C2.3 (I3a), INP_C21.1, RA9.3 (R2.1)
/input/~DBNC_UNK2: C2.13 (I3b), INP_C25.1, RA9.7 (R4.1)
/input/~DBNC_UNK3: B2.3 (I3a), INP_C13.1, RA8.3 (R2.1)
/input/~DBNC_UP: C2.5 (I1a), INP_C22.1, RA6.3 (R2.1)
/~F0-F3_PORT_RD: A2.1 (OEa), A2.15 (OEb), B2.1 (OEa), B2.15 (OEb), C2.1 (OEa), C2.15 (OEb); also elsewhere on the board
/~SWITCH_ACTION: RA1.2 (R1), RA7.2 (R1.2); also elsewhere on the board
/~SWITCH_ACTION2: RA1.6 (R5), RA7.6 (R3.2); also elsewhere on the board
/~SWITCH_COIN1: RA3.2 (R1), RA9.2 (R1.2); also elsewhere on the board
/~SWITCH_COIN2: RA3.7 (R6), RA9.6 (R3.2); also elsewhere on the board
/~SWITCH_DOWN: RA3.6 (R5), RA6.6 (R3.2); also elsewhere on the board
/~SWITCH_LEFT: RA2.2 (R1), RA5.2 (R1.2); also elsewhere on the board
/~SWITCH_RIGHT: RA2.8 (R7), RA5.8 (R4.2); also elsewhere on the board
/~SWITCH_START1: RA2.3 (R2), RA8.2 (R1.2); also elsewhere on the board
/~SWITCH_START2: RA2.9 (R8), RA8.8 (R4.2); also elsewhere on the board
/~SWITCH_TEST: RA1.3 (R2), RA4.2 (R1.2); also elsewhere on the board
/~SWITCH_UNK1: RA3.5 (R4), RA9.4 (R2.2); also elsewhere on the board
/~SWITCH_UNK2: RA3.9 (R8), RA9.8 (R4.2); also elsewhere on the board
/~SWITCH_UNK3: RA2.5 (R4), RA8.4 (R2.2); also elsewhere on the board
/~SWITCH_UP: RA3.4 (R3), RA6.4 (R2.2); also elsewhere on the board
GND: A2.8 (GND), B2.8 (GND), C2.8 (GND), INP_C3.2, INP_C4.2, INP_C7.2, INP_C11.2, INP_C12.2, INP_C13.2, INP_C17.2, INP_C18.2, INP_C19.2, INP_C21.2, INP_C22.2, INP_C23.2, INP_C24.2, INP_C25.2; also elsewhere on the board
unnamed: RA1.4 (R3), RA7.4 (R2.2)
unnamed: RA1.7 (R6), RA4.6 (R3.2)
unnamed: RA1.8 (R7), RA7.8 (R4.2)
unnamed: RA2.6 (R5), RA5.6 (R3.2)
VCC: A2.16 (VCC), B2.16 (VCC), C2.16 (VCC), RA1.1 (common), RA2.1 (common), RA3.1 (common); also elsewhere on the board

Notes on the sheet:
Unused inputs are connected to pull-ups as a precaution

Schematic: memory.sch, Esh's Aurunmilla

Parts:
B8: MB8416-20; DIP-24_W15.24mm_Socket
BAT1: 3-51FT-P, 3.6V; Battery_3-51FT-P
C8: 2764; DIP-28_W15.24mm
CP_B8: 0.1uF; R_Axial_DIN0204_L3.6mm_D1.6mm_P5.08mm_Horizontal
D8: 2764; DIP-28_W15.24mm
DIODE2, DIODE3: 1N4148; D_T-1_P10.16mm_Horizontal
E8: 2764; DIP-28_W15.24mm
F8: 2764; DIP-28_W15.24mm
H8: 2764; DIP-28_W15.24mm
R24: 470; R_Axial_DIN0207_L6.3mm_D2.5mm_P10.16mm_Horizontal
R25: 10k; R_Axial_DIN0207_L6.3mm_D2.5mm_P10.16mm_Horizontal

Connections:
/A0: B8.8 (A0), C8.10 (A0), D8.10 (A0), E8.10 (A0), F8.10 (A0), H8.10 (A0); also elsewhere on the board
/A1: B8.7 (A1), C8.9 (A1), D8.9 (A1), E8.9 (A1), F8.9 (A1), H8.9 (A1); also elsewhere on the board
/A2: B8.6 (A2), C8.8 (A2), D8.8 (A2), E8.8 (A2), F8.8 (A2), H8.8 (A2); also elsewhere on the board
/A3: B8.5 (A3), C8.7 (A3), D8.7 (A3), E8.7 (A3), F8.7 (A3), H8.7 (A3); also elsewhere on the board
/A4: B8.4 (A4), C8.6 (A4), D8.6 (A4), E8.6 (A4), F8.6 (A4), H8.6 (A4); also elsewhere on the board
/A5: B8.3 (A5), C8.5 (A5), D8.5 (A5), E8.5 (A5), F8.5 (A5), H8.5 (A5); also elsewhere on the board
/A6: B8.2 (A6), C8.4 (A6), D8.4 (A6), E8.4 (A6), F8.4 (A6), H8.4 (A6); also elsewhere on the board
/A7: B8.1 (A7), C8.3 (A7), D8.3 (A7), E8.3 (A7), F8.3 (A7), H8.3 (A7); also elsewhere on the board
/A8: B8.23 (A8), C8.25 (A8), D8.25 (A8), E8.25 (A8), F8.25 (A8), H8.25 (A8); also elsewhere on the board
/A9: B8.22 (A9), C8.24 (A9), D8.24 (A9), E8.24 (A9), F8.24 (A9), H8.24 (A9); also elsewhere on the board
/A10: B8.19 (A10), C8.21 (A10), D8.21 (A10), E8.21 (A10), F8.21 (A10), H8.21 (A10); also elsewhere on the board
/A11: C8.23 (A11), D8.23 (A11), E8.23 (A11), F8.23 (A11), H8.23 (A11); also elsewhere on the board
/A12: C8.2 (A12), D8.2 (A12), E8.2 (A12), F8.2 (A12), H8.2 (A12); also elsewhere on the board
/D0: B8.9 (IO0), C8.11 (D0), D8.11 (D0), E8.11 (D0), F8.11 (D0), H8.11 (D0); also elsewhere on the board
/D1: B8.10 (IO1), C8.12 (D1), D8.12 (D1), E8.12 (D1), F8.12 (D1), H8.12 (D1); also elsewhere on the board
/D2: B8.11 (IO2), C8.13 (D2), D8.13 (D2), E8.13 (D2), F8.13 (D2), H8.13 (D2); also elsewhere on the board
/D3: B8.13 (IO3), C8.15 (D3), D8.15 (D3), E8.15 (D3), F8.15 (D3), H8.15 (D3); also elsewhere on the board
/D4: B8.14 (IO4), C8.16 (D4), D8.16 (D4), E8.16 (D4), F8.16 (D4), H8.16 (D4); also elsewhere on the board
/D5: B8.15 (IO5), C8.17 (D5), D8.17 (D5), E8.17 (D5), F8.17 (D5), H8.17 (D5); also elsewhere on the board
/D6: B8.16 (IO6), C8.18 (D6), D8.18 (D6), E8.18 (D6), F8.18 (D6), H8.18 (D6); also elsewhere on the board
/D7: B8.17 (IO7), C8.19 (D7), D8.19 (D7), E8.19 (D7), F8.19 (D7), H8.19 (D7); also elsewhere on the board
/RAM_PWR: B8.24 (VCC), CP_B8.1, DIODE2.1 (K), DIODE3.1 (K), R24.2, R25.2; also elsewhere on the board
/~RAM_B8: B8.18 (~CS), R25.1; also elsewhere on the board
/~RD: B8.20 (~OE), C8.22 (~OE), D8.22 (~OE), E8.22 (~OE), F8.22 (~OE), H8.22 (~OE); also elsewhere on the board
/~ROM_C8: C8.20 (~CE); also elsewhere on the board
/~ROM_D8: D8.20 (~CE); also elsewhere on the board
/~ROM_E8: E8.20 (~CE); also elsewhere on the board
/~ROM_F8: F8.20 (~CE); also elsewhere on the board
/~ROM_H8: H8.20 (~CE); also elsewhere on the board
/~WR: B8.21 (~WE), C8.27 (~PGM), D8.27 (~PGM), E8.27 (~PGM), F8.27 (~PGM), H8.27 (~PGM); also elsewhere on the board
GND: B8.12 (GND), BAT1.2 (-), C8.14 (GND), CP_B8.2, D8.14 (GND), E8.14 (GND), F8.14 (GND), H8.14 (GND); also elsewhere on the board
unnamed: BAT1.1 (+), DIODE3.2 (A), R24.1
VCC: C8.1 (VPP), C8.28 (VCC), D8.1 (VPP), D8.28 (VCC), DIODE2.2 (A), E8.1 (VPP), E8.28 (VCC), F8.1 (VPP), F8.28 (VCC), H8.1 (VPP), H8.28 (VCC); also elsewhere on the board

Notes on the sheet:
Address Bus
Data Bus
When powered on, RAM_PWR is VCC - 0.6V (measured VCC at 4.8V, RAM_PWR at 4.2V) When powered off, RAM_PWR is the battery's voltage
Original battery manufacturer is YUASA
This is the CPU's RAM. Generic 6116 RAM should work as a replacement.


Board: 2 copper layers, 299.7 x 229.9 mm, 188 parts (0 on the bottom side), 330 nets.

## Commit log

2024-06-08 added main Esh PCB - kicad v5 project
    [addrmux.sch, cpu.sch, esh.kicad_pcb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]
2024-06-08 added Esh's sync prom replacement PCB
    [eshSyncPromReplacement.kicad_pcb, eshSyncPromReplacement.sch]
2024-06-08 added Esh color PROM replacement PCB
    [eshColorPromReplacement.kicad_pcb, eshColorPromReplacement.sch]
2024-06-08 added bill of materials files for the three Esh PCBs
    [Esh Bill of Materials.xlsx, Esh Color Prom Replacement - Bill of Materials.xlsx, Esh Sync Prom Replacement - Bill of Materials.xlsx]
2024-06-16 added BofM for LDP and sound cables
    [Esh LDP Cable Bill of Materials.xlsx, Esh Sound Cable Bill of Materials.xlsx]
